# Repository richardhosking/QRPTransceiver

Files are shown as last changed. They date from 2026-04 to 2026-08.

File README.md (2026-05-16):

# QRPTransceiver

QRPTransceiver is an HF transceiver project using phasing techniques, surface-mount components, KiCad hardware design files, and Raspberry Pi Pico firmware for control and user interface.

## Overview

The repository combines:

- **hardware design** in KiCad
- **firmware** for Raspberry Pi Pico using PlatformIO/Arduino
- **local oscillator control** using an SI5351
- **front-panel UI** using a rotary encoder, push buttons, and an ILI9341 TFT display

The design is centered on a phasing-based architecture for HF operation and is being developed as an integrated hardware/firmware system.

## Repository Structure

```text
.
├── firmware/
│   ├── src/                # Main firmware application
│   ├── lib/                # Firmware libraries (UI, input, SI5351 control, etc.)
│   ├── include/            # Shared firmware headers
│   ├── test/               # Firmware tests
│   ├── scripts/            # Utility scripts
│   └── platformio.ini      # PlatformIO project file
├── hardware/
│   ├── kicad/
│   │   ├── QRPTransceiver.kicad_pro
│   │   ├── QRPTransceiver.kicad_sch
│   │   ├── QRPTransceiver.kicad_pcb
│   │   ├── QRPTransceiver.pretty/   # Local footprint library
│   │   └── lib_sch/                 # Local symbol library files
│   └── outputs/            # Manufacturing outputs, exports, and generated artifacts
├── docs/
│   ├── architecture.md
│   ├── bringup.md
│   ├── calibration.md
│   ├── firmware-overview.md
│   ├── hardware-overview.md
│   ├── pinout.md
│   └── summaries/          # Summary notes and rework history
├── reference/
│   ├── datasheets/         # Reference component datasheets
│   └── licenses/           # License/reference documents
├── archive/
│   ├── backups/            # Backup zips, cache/rescue files, and *-bak artifacts
│   ├── legacy-kicad/       # Legacy KiCad schematic/netlist files
│   └── temporary/          # Autosave, lock, and temporary design files
└── README.md
```

The repository is now organized so that active firmware lives under `firmware/`, the active KiCad project lives under `hardware/kicad/`, generated hardware outputs live under `hardware/outputs/`, and reference material is stored under `reference/`.

## Main Subsystems

### Hardware
- main transceiver schematic and PCB
- hierarchical sheets for mixer, polyphase, and receiver audio sections
- local symbol and footprint libraries
- manufacturing outputs and design reports

### Firmware
- `firmware/src/main.cpp` as the control entry point
- `firmware/lib/DisplayUI` for the TFT display layer
- `firmware/lib/RotaryInput` for tuning encoder input
- `firmware/lib/PushButtons` for front-panel button handling
- `firmware/lib/SI5351Control` for synthesizer control and band-specific quadrature setup

## Documentation

Project documentation is organized under `docs/`:

- `docs/architecture.md` — overall system architecture
- `docs/bringup.md` — bring-up notes and observations
- `docs/calibration.md` — calibration workflow and notes
- `docs/hardware-overview.md` — hardware design structure and subsystem roles
- `docs/firmware-overview.md` — firmware organization and responsibilities
- `docs/pinout.md` — firmware-visible pin assignments
- `docs/summaries/` — summary notes for key refactors, programming flow, and quadrature correction work

## Current Status

The repository currently contains:
- active KiCad project files under `hardware/kicad/`
- firmware for Pico-based control and display under `firmware/`
- generated outputs under `hardware/outputs/`
- reference materials under `reference/`
- archived legacy, backup, and intermediate design artifacts under `archive/`

As the project evolves, the active KiCad project and PlatformIO firmware remain the primary editable sources in their dedicated subdirectories.

## Toolchain

### Hardware
- KiCad 8 project files are present under `hardware/kicad/`

### Firmware
- PlatformIO
- Arduino framework for Raspberry Pi Pico
- SI5351 library
- Adafruit GFX / ILI9341 display libraries

## Notes

This project is an active mixed-domain design spanning:

- RF/analog circuit design
- phasing-based transceiver architecture
- embedded firmware
- user interface development
- calibration and layout refinement

For architectural details, start with `docs/architecture.md`.

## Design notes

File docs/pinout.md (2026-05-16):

# QRPTransceiver Pinout

## 1. Scope

This document summarizes the firmware-visible pin assignments currently used by QRPTransceiver. These values are derived from the current firmware source and should be treated as the active software pin map unless hardware wiring is intentionally changed.

## 2. Raspberry Pi Pico Pin Usage Summary

## 2.1 Rotary encoder

- GP2 — rotary encoder A
- GP3 — rotary encoder B
- GP6 — rotary encoder push button

## 2.2 Front-panel buttons

- GP7 — MODE button
- GP8 — BAND button
- GP9 — STEP button
- GP10 — FN/SAVE button

## 2.3 TFT display

- GP16 — TFT MISO
- GP17 — TFT CS
- GP18 — TFT SCK
- GP19 — TFT MOSI
- GP20 — TFT DC
- GP21 — TFT RST
- GP22 — TFT backlight

## 2.4 Built-in indicator

- LED_BUILTIN — firmware heartbeat indicator

## 3. Functional Grouping

### User input
- GP2, GP3, GP6
- GP7, GP8, GP9, GP10

### Display / SPI-related
- GP16, GP17, GP18, GP19, GP20, GP21, GP22

### System status
- LED_BUILTIN

## 4. Notes

## 4.1 Input assumptions

The current firmware configures:

- rotary encoder pins with pull-ups
- encoder button with pull-up
- push buttons as active-low inputs with pull-ups

This means external wiring should match an active-low switch arrangement unless the firmware configuration is changed.

## 4.2 Push-button defaults

The push-button library default configuration supports:

- MODE
- BAND
- STEP
- FN

The main application currently initializes FN on GP10.

## 4.3 Display assumptions

The display layer is written for an ILI9341-compatible TFT and uses the pin assignments listed above. The firmware also references display probe reads and a landscape orientation UI.

## 4.4 SI5351 interface

The current firmware clearly initializes the SI5351, but the specific GPIO pins used for its control bus are not explicitly documented in the currently reviewed source snippets. On Raspberry Pi Pico Arduino builds, these may rely on the framework's default I2C pin mapping unless overridden elsewhere.

That interface should be documented explicitly once confirmed in the hardware or complete firmware configuration.

## 5. Recommended Next Step

This file should eventually be expanded with:

- SI5351 bus pins
- power-related pins if relevant
- connector names
- schematic reference designators for major interfaces
- a table cross-referencing Pico pin numbers, GPIO names, and physical connector locations

## 6. Summary Table

| Function | GPIO |
|---|---|
| Encoder A | GP2 |
| Encoder B | GP3 |
| Encoder Button | GP6 |
| MODE Button | GP7 |
| BAND Button | GP8 |
| STEP Button | GP9 |
| FN/SAVE Button | GP10 |
| TFT MISO | GP16 |
| TFT CS | GP17 |
| TFT SCK | GP18 |
| TFT MOSI | GP19 |
| TFT DC | GP20 |
| TFT RST | GP21 |
| TFT Backlight | GP22 |
| Heartbeat LED | LED_BUILTIN |

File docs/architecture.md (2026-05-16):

# QRPTransceiver Architecture

## 1. Purpose

QRPTransceiver is a low-power HF transceiver project that combines:

- an analog phasing-based RF/baseband architecture
- SI5351-based local oscillator generation
- Raspberry Pi Pico digital control
- a TFT-based user interface
- KiCad hardware design files and PlatformIO-based firmware

The repository currently contains both the hardware design and the firmware used to control the synthesizer, user input devices, and display.

## 2. Project Goals

The current design appears to target the following goals:

- build a compact HF SSB transceiver
- use phasing techniques rather than a conventional crystal IF
- support multiple amateur HF bands
- provide digitally controlled tuning and band/mode selection
- use low-cost and widely available components
- keep the firmware modular enough to separate UI, tuning input, and synthesizer control

## 3. High-Level System Overview

At a high level, the system is organized into these major subsystems:

1. **RF and analog signal path**
   - receives and processes RF signals
   - performs phasing/mixing operations
   - routes signal energy through receiver audio/baseband stages

2. **Quadrature frequency generation**
   - generates the LO signals required by the phasing architecture
   - uses the SI5351 clock generator as the main frequency source
   - applies band-specific quadrature setup logic in firmware

3. **Control firmware**
   - maintains VFO frequency, band, and mode state
   - handles persistent settings storage
   - coordinates synthesizer, display, buttons, and rotary input

4. **User interface**
   - presents frequency and mode information on an ILI9341 TFT display
   - allows tuning and control through a rotary encoder and push buttons

5. **Hardware documentation and manufacturing outputs**
   - KiCad schematic and PCB files
   - generated Gerbers, PDFs, and reports
   - reference datasheets and design notes

## 4. Repository-Level Architecture

The repository contains two tightly coupled but distinct domains:

### 4.1 Hardware design domain

The hardware domain is centered on KiCad project files, including:

- main project and board files
- top-level hierarchical schematic
- subsystem schematics such as mixer, polyphase, and receiver audio sections
- PCB layout
- footprint and symbol libraries
- manufacturing outputs and reports

This domain defines the transceiver's electrical implementation and board layout.

### 4.2 Firmware domain

The firmware domain is a PlatformIO/Arduino-style codebase for Raspberry Pi Pico. It contains:

- application entry point in `src/`
- reusable libraries in `lib/`
- headers in `include/`
- scripts and tests
- configuration in `platformio.ini`

This domain implements the runtime behavior of the transceiver controller.

## 5. Hardware Architecture

## 5.1 Top-level schematic structure

The KiCad top-level schematic is organized using hierarchical sheets. The important hardware blocks currently visible in the design are:

- main transceiver sheet
- mixer section
- polyphase section
- receiver audio section

This indicates a design where the signal path is intentionally partitioned into functional analog subsystems.

## 5.2 RF / phasing concept

The project is described as an **SSB HF transceiver using phasing techniques**. In practical terms, this implies:

- quadrature-related signal generation and processing are central to the design
- the mixer and polyphase sections are likely responsible for phase relationships used to reject the unwanted sideband
- sideband suppression depends on maintaining amplitude and phase accuracy across the signal chain

Because phasing architectures are sensitive to imbalance, calibration and layout discipline are important parts of the overall architecture.

## 5.3 Main analog subsystems

### Mixer subsystem

The mixer subsystem is expected to:

- combine RF and local oscillator signals
- generate or recover quadrature baseband/audio components
- participate in sideband selection or rejection depending on signal direction

This block should be treated as one of the primary RF-critical sections of the design.

### Polyphase subsystem

The polyphase subsystem is expected to:

- generate or process 90-degree phase-shifted signals
- support phasing-based image or sideband cancellation
- define frequency-sensitive analog behavior that may need tuning or characterization

This is a core architectural block for any phasing transceiver.

### Receiver audio subsystem

The receiver audio subsystem is expected to:

- filter and amplify low-frequency recovered signals
- condition audio for monitoring or downstream processing
- provide an analog endpoint for receive-path verification during bring-up

This block is a natural place for gain shaping, filtering, and audio output conditioning.

## 5.4 PCB architecture

The PCB file indicates the project includes a board layout and manufacturing outputs. At an architectural level, the PCB should be understood as containing at least these physical partitions:

- RF-sensitive analog paths
- local oscillator / clock routing
- audio/baseband analog stages
- digital control and display connections
- power distribution and grounding

For maintainability and performance, the layout should preserve clear separation between noisy digital circuits and sensitive analog/RF sections.

## 6. Frequency Generation and Synthesizer Architecture

## 6.1 SI5351 as the main LO source

The firmware includes a dedicated `SI5351Control` library. This makes the SI5351 the primary digital frequency source for the transceiver.

Responsibilities of this subsystem include:

- initializing the SI5351
- setting VFO frequency
- enabling/disabling outputs
- configuring band-specific quadrature behavior
- exposing synthesizer readiness and current frequency state

## 6.2 Band-aware quadrature control

The synthesizer code defines band profiles for amateur bands including:

- 160 m
- 80 m
- 40 m
- 30 m
- 20 m
- 17 m
- 15 m
- 12 m
- 10 m

This suggests that quadrature generation is not handled as a single generic configuration but is tuned using precomputed band profiles.

Architecturally, this is important because it means:

- the LO subsystem contains band-specific knowledge
- frequency generation and phase behavior are part of the firmware design, not only hardware
- calibration may differ by band

## 6.3 Frequency correction model

The firmware includes a crystal correction value in parts-per-billion. This means the architecture already acknowledges oscillator error and compensates it in software.

This is a strong architectural choice because it allows:

- post-assembly calibration
- compensation for crystal tolerance
- easier alignment without hardware modification

## 7. Firmware Architecture

## 7.1 Firmware responsibilities

The firmware acts as the control plane for the transceiver. It is responsible for:

- initializing hardware peripherals
- maintaining tuning state
- managing frequency bands and step sizes
- controlling the display
- reading user input
- storing and restoring persistent settings
- programming the SI5351 synthesizer

The firmware is not just a UI layer; it is the coordination layer that makes the analog hardware usable as a complete radio.

## 7.2 Main application layer

The main application code in `src/main.cpp` appears to manage:

- current VFO frequency
- current operating mode
- allowed tuning range
- step sizes
- default frequencies per band
- current band index
- dirty-state tracking for persistent settings

This is effectively the system state model of the transceiver.

## 7.3 Library-based modularity

The firmware already uses separate libraries for major functions:

### DisplayUI

Responsibilities:

- initialize and access the ILI9341 display
- configure orientation and display settings
- render splash and main screens
- update frequency and mode display fields

This module is the presentation layer.

### RotaryInput

Responsibilities:

- initialize the rotary encoder interface
- decode Gray-code transitions
- detect button presses
- control tuning step size

This module is the primary tuning input layer.

### PushButtons

Responsibilities:

- read additional front-panel buttons
- support mode, band, and step selection
- provide button events to the main application layer

### SI5351Control

Responsibilities:

- initialize clock generation
- apply band-specific profiles
- set VFO frequency
- manage output enable state
- report synthesizer status

This module is the frequency-control layer.

## 7.4 Persistent settings

The main firmware includes flash-backed settings with a magic value and version field. Architecturally, this means the transceiver preserves user state across power cycles.

Likely persistent state includes:

- selected band
- per-band frequencies
- current tuning configuration
- other user preferences as the firmware evolves

This is a good fit for a radio UI, since users expect frequency memories and last-used settings to be retained.

## 8. User Interface Architecture

## 8.1 Physical controls

The interface includes:

- a rotary encoder with push button
- three additional push buttons
- a TFT display

This creates a compact front-panel interaction model suitable for a small transceiver.

## 8.2 Display model

The UI library currently supports:

- splash screen
- main operating screen
- frequency display updates
- mode display
- status bar regions
- placeholder S-meter area

This suggests a screen architecture based on a single main operating view rather than a menu-heavy system.

## 8.3 UI state and operating model

The present interaction model appears to be:

- rotary encoder changes VFO frequency
- button actions change step, mode, or band
- screen redraws reflect current operating state

A future evolution could formalize this into an explicit UI state machine, but the current architecture is suitable for a single-purpose front panel.

## 9. Operating Modes and Band Model

The current mode model includes:

- LSB
- USB
- CW
- FT8
- WSPR

This is an interesting architectural choice because it separates **display/operating intent** from pure RF hardware details. It suggests the firmware is intended to support multiple operating styles, even if some modes share the same underlying analog path.

The band model currently includes amateur band defaults and remembers a working frequency per band. This is a practical radio control feature and should remain a first-class concept in the architecture.

## 10. Data and Control Flow

## 10.1 Control flow from user input to frequency output

A typical tuning flow is:

1. user rotates encoder
2. rotary module produces a step delta
3. main application applies the selected tuning step
4. VFO frequency is updated
5. synthesizer is reprogrammed
6. display is updated to reflect the new frequency and mode

This path is the central interaction loop of the system.

## 10.2 Control flow for band/mode changes

A typical band or mode change flow is:

1. user presses a control button
2. main application updates current mode or band index
3. band default or stored band frequency is restored
4. synthesizer is reconfigured if needed
5. display is refreshed

## 10.3 Boot flow

A probable boot sequence is:

1. initialize MCU runtime
2. initialize display and draw splash screen
3. initialize input devices
4. load persistent settings from flash
5. initialize SI5351 with configured correction
6. apply default or restored VFO frequency and mode
7. draw main screen

## 11. Calibration Architecture

Calibration is not an optional add-on for this design; it is part of the architecture.

Important calibration concerns include:

- SI5351 absolute frequency correction
- quadrature phase accuracy
- gain balance between I/Q or phasing paths
- sideband suppression verification
- per-band behavior

The existing crystal correction approach shows that firmware-assisted calibration is already part of the design philosophy.

A dedicated calibration procedure document should exist alongside this architecture.

## 12. Design Constraints and Tradeoffs

The design appears to balance several constraints:

### Low-cost and availability
Using Raspberry Pi Pico, SI5351, and common display modules keeps the platform accessible.

### Simplicity vs. performance
A phasing architecture can reduce reliance on IF filters but introduces sensitivity to analog balance and calibration.

### Modular firmware
The firmware is organized cleanly into libraries, which supports iterative improvement.

### Mixed-domain complexity
The project spans analog RF design, phasing concepts, digital control, PCB layout, and UI, which means architectural clarity is especially important.

## 13. Known Architectural Gaps

Based on the current repository, these areas need clearer design documentation:

- explicit receive signal path description
- whether transmit is already implemented in hardware or only planned
- exact relationship between quadrature synthesis and analog phasing network
- power architecture and regulator scheme
- front-panel control mapping
- calibration workflow by band
- test strategy for RF, LO, and audio subsystems

These gaps do not necessarily reflect design problems, but they do reduce maintainability and onboarding ease.

## 14. Recommended Canonical Architecture Organization

To make the architecture easier to maintain, the repository should treat the following as canonical:

### Hardware source of truth
- current KiCad 8 project files
- hierarchical schematics
- current PCB layout
- local symbol and footprint libraries

### Firmware source of truth
- `platformio.ini`
- `src/`
- `lib/`
- `include/`
- `test/`

### Generated outputs
- Gerbers
- PDFs
- DRC reports

### Archived artifacts
- old KiCad legacy-format files
- autosaves
- backups
- copied project files
- cache files

## 15. Recommended Next Documentation

This architecture file should be accompanied by:

- `docs/hardware-overview.md`
- `docs/firmware-overview.md`
- `docs/bringup.md`
- `docs/calibration.md`
- `docs/pinout.md`
- `docs/block-diagram.md`

## 16. Summary

QRPTransceiver is a mixed hardware/firmware transceiver project built around a phasing-based HF architecture. Its defining characteristics are:

- analog phasing signal processing
- SI5351-based quadrature-oriented local oscillator control
- Raspberry Pi Pico-based digital coordination
- modular firmware for UI, tuning input, and synthesizer control
- integrated KiCad board and schematic design files

The project already has a solid modular foundation in both hardware hierarchy and firmware library structure. The main architectural need now is not a redesign of the system itself, but clearer documentation, stronger separation of canonical files from generated or legacy artifacts, and explicit documentation of signal flow, calibration, and subsystem boundaries.

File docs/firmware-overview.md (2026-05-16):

# QRPTransceiver Firmware Overview

## 1. Scope

This document describes the structure and responsibilities of the QRPTransceiver firmware. The firmware runs on a Raspberry Pi Pico and provides the control layer for tuning, user interaction, display output, and SI5351 frequency generation.

## 2. Firmware Role in the System

The firmware is the operational control plane of the transceiver. It is responsible for making the hardware usable as a radio by coordinating:

- VFO tuning
- band selection
- operating mode selection
- synthesizer configuration
- user input handling
- front-panel display output
- persistent settings storage

Without the firmware, the hardware design is a set of subsystems; with the firmware, those subsystems become an interactive transceiver platform.

## 3. Firmware Technology Stack

The repository indicates a firmware stack based on:

- Raspberry Pi Pico
- PlatformIO
- Arduino-compatible framework
- external device libraries for the display and SI5351

The code is structured in a modular embedded style rather than as a single monolithic application file.

## 4. Repository Layout

The firmware-related repository structure currently includes:

- `src/` — application entry point and top-level behavior
- `lib/` — modular libraries for display, rotary input, buttons, and synthesizer control
- `include/` — shared headers
- `test/` — tests
- `scripts/` — helper scripts
- `platformio.ini` — firmware build and configuration entry point

This is a good foundation for maintainable firmware development.

## 5. Main Responsibilities

The firmware currently appears to implement these major responsibilities:

### 5.1 System initialization
- initialize runtime and peripherals
- initialize display
- initialize input devices
- initialize SI5351 synthesizer
- restore or initialize operating state

### 5.2 Frequency control
- maintain the current VFO frequency
- apply minimum and maximum tuning limits
- support different tuning step sizes
- remember working frequencies for each band

### 5.3 Mode and band control
- track current operating mode
- change band defaults or stored band frequencies
- update display and synthesizer state after control changes

### 5.4 User interface control
- render splash and main screens
- update frequency and mode display fields
- reflect transceiver state visually

### 5.5 Persistent settings
- save settings to flash
- restore settings at boot
- track dirty state and versioning

## 6. Main Application Architecture

## 6.1 `src/main.cpp`

The main application layer acts as the system coordinator. It appears to hold or manage:

- current VFO frequency
- current mode
- valid tuning range
- tuning step table
- band default frequencies
- currently selected band
- settings persistence metadata

This file is the central state-management and orchestration layer of the firmware.

## 6.2 Application state model

The firmware already has the beginnings of a coherent state model. Important state elements include:

- current frequency
- current mode
- current band
- selected tuning step
- per-band stored frequencies
- settings dirty flag

This state should be treated as the canonical runtime model for the transceiver.

## 7. Modular Library Architecture

The firmware is split into reusable libraries under `lib/`. This is one of the strongest parts of the current design.

## 7.1 DisplayUI

The `DisplayUI` module is responsible for the front-panel display layer.

Current responsibilities include:

- providing access to the display instance
- display initialization
- reading display probe data
- UI configuration
- drawing splash and main screens
- updating the visible frequency and mode

Architecturally, this module should remain focused on presentation rather than business logic.

### Recommended boundary
`DisplayUI` should:
- draw UI state
- format visual elements
- own screen layout details

`DisplayUI` should not:
- decide operating policy
- own VFO truth
- perform synthesizer logic

## 7.2 RotaryInput

The `RotaryInput` module handles tuning encoder behavior.

Current responsibilities include:

- GPIO setup for encoder pins
- Gray-code decoding
- directional step detection
- encoder button edge detection
- tuning step value management

Architecturally, this module is the low-level physical input decoder for the main tuning control.

### Recommended boundary
`RotaryInput` should:
- read hardware state
- return delta steps and button events

`RotaryInput` should not:
- directly change frequency
- directly update the display
- contain band or mode logic

## 7.3 PushButtons

The `PushButtons` module is intended to handle the additional front-panel buttons.

Expected responsibilities include:

- reading non-encoder button states
- debouncing or edge detection
- converting button actions into application-level events

This module should be the companion input layer to the rotary encoder.

## 7.4 SI5351Control

The `SI5351Control` module is responsible for the programmable oscillator subsystem.

Current responsibilities include:

- initializing the SI5351
- accepting configuration such as crystal frequency and correction
- setting VFO frequency
- configuring quadrature-related output behavior
- applying band-specific profiles
- enabling or disabling outputs
- reporting readiness and current VFO value

This module is the firmware's abstraction over the LO hardware.

### Recommended boundary
`SI5351Control` should:
- own synthesizer device behavior
- translate desired frequency state into SI5351 operations
- contain band profile and correction logic

`SI5351Control` should not:
- own screen rendering
- own button interpretation
- decide UI workflow

## 8. Operating Model

## 8.1 Tuning workflow

The normal tuning loop is expected to be:

1. read encoder movement
2. convert movement into signed tuning steps
3. scale by selected tuning resolution
4. clamp to valid range
5. update VFO state
6. program SI5351 to new frequency
7. refresh display

This is the highest-frequency control loop in the application.

## 8.2 Band-change workflow

The normal band-change flow is expected to be:

1. detect button event
2. increment or select band
3. restore stored or default frequency for that band
4. apply synthesizer configuration changes
5. update visible UI fields

## 8.3 Mode-change workflow

The normal mode-change flow is expected to be:

1. detect button event
2. update mode state
3. refresh any derived behavior or display fields
4. keep the mode visible on the main screen

## 9. Frequency and Band Model

The firmware includes:

- a valid tuning range from low HF through 6 m
- a step table with multiple resolutions
- default frequencies for multiple amateur bands
- retained per-band frequency state

This is a sound operating model for a compact radio because it allows:

- quick tuning changes
- predictable band recall
- user-friendly control behavior

## 10. Persistent Settings Architecture

The firmware includes flash-backed settings identified by:

- a magic value
- a version field

This is the right foundation for reliable on-device persistence.

A robust persisted settings model should eventually include:

- current band
- current frequency or per-band frequencies
- tuning step selection
- selected mode
- calibration/configuration values if appropriate

Versioning is important so settings can evolve safely as firmware changes.

## 11. UI Architecture

## 11.1 Current UI model

The current display model appears to center on a single primary operating screen with:

- frequency display
- mode area
- band area
- status bar
- S-meter placeholder

This is well suited to a compact hardware front panel.

## 11.2 Recommended UI layering

The UI architecture will remain easier to maintain if it is split conceptually into:

### View model
A simple representation of what should be shown:
- frequency text
- mode text
- band text
- status fields

### Rendering layer
The actual display drawing code in `DisplayUI`

### Application controller
Main logic that decides when the view model changes

This reduces coupling between control logic and drawing logic.

## 12. Error Handling and Robustness

Firmware for a radio controller should handle at least these fault conditions gracefully:

- SI5351 initialization failure
- display initialization or communication problems
- invalid or corrupt flash settings
- out-of-range frequency requests
- input bounce or noisy encoder transitions

The current modular architecture makes it practical to improve robustness incrementally.

## 13. Recommended Future Refactoring Directions

The current structure is already solid, but future improvements could include:

### 13.1 Explicit application state struct
Move global state into a structured object such as:
- VFO
- band
- mode
- step
- persistent settings metadata

### 13.2 Event-driven input handling
Represent button and encoder actions as explicit events rather than direct inline mutations.

### 13.3 UI view model
Create a lightweight UI data model that the renderer consumes.

### 13.4 Hardware abstraction consistency
Ensure all hardware-facing code stays inside dedicated modules rather than leaking into `main.cpp`.

### 13.5 Centralized calibration/config structure
Store synthesizer correction, band offsets, and similar tunable values in a dedicated configuration layer.

## 14. Testing Opportunities

The presence of a `test/` directory means the project can grow into more systematic validation. Useful firmware tests would include:

- step-size logic
- frequency clamping
- band-memory behavior
- mode cycling behavior
- settings serialization/deserialization
- band profile selection logic
- frequency formatting for display

Even if hardware access remains manual, core logic can be validated independently.

## 15. Recommended Firmware Documentation Additions

In addition to this overview, useful companion documents would be:

- `docs/pinout.md`
- `docs/bringup.md`
- `docs/calibration.md`
- `docs/ui-behavior.md`
- `docs/settings-format.md`

## 16. Summary

The QRPTransceiver firmware is a modular embedded control system for a phasing-based HF transceiver. Its central role is to coordinate:

- tuning and band/mode state
- SI5351 frequency generation
- user input from encoder and buttons
- ILI9341 display output
- persistence of radio operating state

The current separation into `DisplayUI`, `RotaryInput`, `PushButtons`, and `SI5351Control` is a strong architectural base. The main next steps are clearer documentation, slightly more explicit state modeling, and continued separation between application logic, rendering, and hardware control.

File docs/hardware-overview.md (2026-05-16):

# QRPTransceiver Hardware Overview

## 1. Scope

This document describes the hardware organization of the QRPTransceiver project at the repository and subsystem level. It is intended as a guide to how the hardware design is partitioned, what the major blocks are, and how to navigate the KiCad sources.

## 2. Hardware Design Artifacts

The hardware design currently includes:

- KiCad project file
- top-level schematic
- PCB layout
- hierarchical schematic sheets
- local footprint and symbol libraries
- Gerber outputs
- PDF exports
- DRC and related reports
- datasheet references

These files collectively define the electrical design, physical PCB implementation, and manufacturing outputs.

## 3. Primary Hardware Source Files

The main editable hardware sources should be treated as:

- `QRPTransceiver.kicad_pro`
- `QRPTransceiver.kicad_sch`
- `QRPTransceiver.kicad_pcb`

These should be considered the primary design source of truth.

Additional subsystem schematics currently include:

- `ReceiverAudio.kicad_sch`
- `polyphase.kicad_sch`

The top-level schematic also references additional hierarchical sheet structure for mixer-related circuitry.

## 4. Design Philosophy

The hardware appears to follow a phasing-based HF transceiver approach. This implies a design philosophy built around:

- quadrature signal generation or processing
- analog amplitude and phase balance
- modular RF/baseband partitioning
- digital assistance for tuning and control
- practical PCB implementation using surface-mount components

Compared with a more traditional IF-filter-centered transceiver, this architecture places more importance on phase accuracy and subsystem matching.

## 5. Hardware Partitioning

The design can be understood as a set of major hardware blocks.

## 5.1 RF front end

The RF front end is expected to include:

- antenna-side signal entry
- input filtering or band-dependent response
- routing into the mixer/phasing path
- any switching required between operating conditions

This is the section most exposed to external RF conditions and should be treated as a sensitive analog block.

## 5.2 Mixer section

The mixer section is a central transceiver block. Its role is expected to include:

- translation between RF and lower-frequency signal domains
- interaction with quadrature local oscillator signals
- support for sideband-selective behavior through phasing techniques

This section is tightly coupled to the quality of the LO generation and the analog balance of the signal path.

## 5.3 Polyphase section

The polyphase section is one of the defining features of the design. It is expected to:

- establish controlled phase relationships between signal paths
- contribute to image or sideband suppression
- shape the frequency-dependent phase behavior required by the phasing architecture

This block is likely one of the most performance-sensitive parts of the analog design.

## 5.4 Receiver audio section

The receiver audio section is expected to:

- process recovered low-frequency or audio-band signals
- apply filtering and gain
- provide output suitable for listening, measurement, or further conditioning

This block is a key bring-up checkpoint because it allows observation of downconverted receive-path behavior.

## 5.5 Control and digital interface section

The design also includes a digital control domain built around a Raspberry Pi Pico and peripheral modules. This section likely includes:

- MCU connections
- SI5351 control interface
- display connections
- rotary encoder input
- push-button input
- power and reset support for digital peripherals

Although digital, this section directly influences RF usability through frequency control and operating-state selection.

## 6. Frequency Generation Hardware

## 6.1 SI5351 role

The SI5351 is the central programmable oscillator element in the design. Its hardware role is to provide the clock or LO signals required by the transceiver.

In a phasing design, this is especially important because the quality and phase relationship of generated signals directly affect sideband suppression and tuning usability.

## 6.2 Quadrature implications

The firmware organization suggests the hardware depends on band-specific quadrature behavior. That implies the hardware and firmware together form a combined frequency-generation subsystem rather than fully independent analog and digital sections.

This combined subsystem should be treated as a unified design concern during:
- bring-up
- calibration
- troubleshooting
- future revisions

## 7. PCB-Level Considerations

## 7.1 Physical separation of domains

For best performance, the board should maintain clear physical separation between:

- RF analog paths
- audio/baseband analog paths
- clock/LO routing
- digital control and display wiring
- power conversion or regulation areas

This reduces the risk of digital noise degrading analog performance.

## 7.2 Grounding and return paths

Because the project combines analog RF and digital control on one board, grounding strategy is likely to be a key factor in performance. Review areas should include:

- return current paths
- analog/digital interaction zones
- display and SPI noise coupling
- oscillator signal reference quality
- audio-stage grounding

## 7.3 Routing priorities

Routing priorities should generally favor:

- short and controlled LO paths
- clean sensitive analog routing
- separation of switching digital lines from high-gain analog stages
- careful placement of decoupling components
- consistent grounding around the mixer and polyphase networks

## 8. Hardware Interfaces

The major hardware interfaces in the project are expected to include:

### RF interfaces
- antenna and RF signal path connections
- any band-related or signal-routing interconnects

### Audio interfaces
- receiver audio output
- internal analog handoff points between mixer/polyphase/audio sections

### Digital control interfaces
- I2C or similar control connection to SI5351
- SPI connection to TFT display
- GPIO for encoder and buttons

### Power interfaces
- primary supply input
- regulated rails for analog and digital sections
- display backlight and digital peripheral supply distribution

## 9. Bring-Up Strategy by Hardware Block

A practical hardware validation order is:

1. **power rails**
   - confirm supply integrity and regulator outputs

2. **MCU and control section**
   - verify Pico boots and firmware runs

3. **display and inputs**
   - verify user interface hardware functions

4. **SI5351 / LO section**
   - verify oscillator programming and output frequency

5. **receiver audio path**
   - confirm analog audio stages are alive and stable

6. **mixer and quadrature network**
   - verify expected translation and phase-related behavior

7. **full receive chain**
   - validate end-to-end tuning and signal reception

This staged bring-up reduces ambiguity during troubleshooting.

## 10. Hardware Risks and Sensitivities

The most likely architecture-level hardware sensitivities are:

- quadrature phase accuracy
- gain or component tolerance mismatch across phasing paths
- oscillator frequency error
- coupling from digital display/control lines into analog sections
- grounding/layout effects on sideband suppression
- variation in performance across bands

These are normal concerns for a phasing-based mixed-signal transceiver and should be explicitly measured during testing.

## 11. Recommended Hardware Documentation Additions

The hardware design would benefit from dedicated supporting documents such as:

- `docs/block-diagram.md`
- `docs/pinout.md`
- `docs/power.md`
- `docs/calibration.md`
- `docs/bringup.md`
- `docs/layout-notes.md`

In addition, the top-level schematic hierarchy should use clearly descriptive sheet names so the functional structure is visible directly inside KiCad.

## 12. Recommended Canonical Hardware Organization

As the repo evolves, the hardware should ideally be organized so that:

- active KiCad 8 files are grouped together
- generated outputs are separated from source design files
- local libraries are clearly grouped
- archived backups and legacy KiCad files are moved out of the active design path
- reports and exports are treated as generated artifacts rather than editable design source

A future structure could look like:

```text
hardware/
  kicad/
    QRPTransceiver.kicad_pro
    QRPTransceiver.kicad_sch
    QRPTransceiver.kicad_pcb
    sheets/
    libraries/
  outputs/
    gerbers/
    pdf/
    drc/
reference/
  datasheets/
archive/
  legacy-kicad/
  backups/
```

## 13. Summary

The QRPTransceiver hardware is organized around a phasing-based HF transceiver architecture with a strong division between:

- mixer and phasing circuitry
- receiver audio processing
- programmable LO generation
- digital control and user interface

Its success depends not only on correct schematic connectivity, but also on careful quadrature behavior, calibration, and PCB partitioning between analog and digital domains.

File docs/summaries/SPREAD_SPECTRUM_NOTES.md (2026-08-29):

 # Si5351 Spread-Spectrum (SSC) Notes

Last edited: 29 August 2026

Overview
--------
These notes collect the investigation, observed behaviour, and recommended
actions related to spread-spectrum clocking (SSC) on Si5351 modules encountered
during development of the QRPTransceiver firmware.

Background
----------
- Several Si5351 modules in the field and in development were found to power
  up with non-zero SSC parameter registers. The Etherkit `Si5351` library used
  by this project does not expose or manage SSC parameters.
- When active, SSC can impart deterministic spread or sidebands around the
  output clock that appeared as fixed-offset spurs in the receiver spectrum.

What we observed
----------------
- Fixed-offset sidebands (tens of kHz in these modules) that tracked with
  certain tuning operations and output drive transitions.
- After clearing all SSC parameter registers (registers `149..161`) the
  prominent sidebands disappeared and tuning noise characteristics improved.

What we changed (current firmware)
----------------------------------
- On init, the firmware explicitly writes `0x00` to `SI5351_SSC_PARAM0`..`SI5351_SSC_PARAM12`.
  This ensures SSC is effectively disabled for modules that power up with SSC
  enabled. The change is in `lib/SI5351Control/src/SI5351Control.cpp`.

Pros and cons of the current approach
-------------------------------------
- Pros:
  - Simple and reliable: clears any previously-enabled SSC quickly.
  - Eliminated the fixed sidebands observed during testing.

- Cons / Risks:
  - It's a blunt instrument: zeroing all SSC parameters removes any
    intentionally configured SSC behaviour and may hide vendor-specific
    calibration values.
  - Different module vendors may implement SSC-related behaviours slightly
    differently; overwriting all SSC parameters is not guaranteed to be
    appropriate for every board.

Recommended alternatives
------------------------
1. Selective disable
   - Prefer reading the SSC parameter registers at init and selectively
     clearing only the SSC enable/control bits per the SiLabs AN619 description
     if available. This preserves other SSC tuning parameters while disabling
     the spreading behaviour.

2. Preserve & log
   - Read SSC parameter registers on first boot, stash the original values in
     flash or in the serial log, then clear only the enable fields. This gives
     a reproducible rollback path for debugging.

3. External reference
   - If absolute spectral purity is a priority for production units, consider
     switching to an external reference (CLKIN) or using a higher-grade XO or
     TCXO; then set the Si5351 ref/correction appropriately.

Helpful engineering checks
-------------------------
- Read current SSC registers (example pseudo):

  ```cpp
  for (uint8_t r = SI5351_SSC_PARAM0; r <= SI5351_SSC_PARAM12; ++r) {
    Serial.print(r); Serial.print(": ");
    Serial.println(si5351_read(r), HEX);
  }
  ```

- If you see non-zero values, consider logging them before clearing.

Where to from here
-------------------
- I can implement any of the alternatives above:
  - selective disable (read/modify/write of specific bits),
  - persistent backup of SSC values to flash before clearing,
  - or a small serial calibration tool to read/write registers interactively.

If you'd like, tell me which option you prefer and I will implement it and
open a PR with the changes.

References
----------
- Silicon Labs AN619 application note (Si5351 programming guidance)
- Etherkit Si5351 library (no SSC management exposed)
SPREAD SPECTRUM NOTES
=====================

Summary
-------
Some SI5351 modules come from different vendors with spread-spectrum (SSC) features
enabled by default. This can add AM-like sidebands (observed at ±31.5 kHz) on the LO.

Mitigation
----------
- The firmware explicitly clears the SI5351 SSC parameter registers at init to ensure
  spread-spectrum is disabled on modules that power up with it enabled. The register
  range cleared is `SI5351_SSC_PARAM0` .. `SI5351_SSC_PARAM12` (addresses 149..161).
- This is a pragmatic fix; clearing SSC changes the synthesizer behaviour and will
  alter absolute-frequency calibration. The firmware therefore exposes a trim
  (`SI5351_CORRECTION_TRIM_PPB`) that can be adjusted per-board to restore
  absolute frequency accuracy after SSC is disabled.

Open Questions / Follow-ups
---------------------------
- Clearing the full parameter block is aggressive — a cleaner approach would be to
  read-modify-write only the SSC enable bit if the device supports it. This would
  preserve other SSC parameters while ensuring SSC is disabled.
- Consider adding an automated calibration routine to measure and persist the
  `SI5351_CORRECTION_TRIM_PPB` per board to account for module-to-module variation
  and temperature drift.

References
----------
- Etherkit Si5351 headers define the SSC registers but the library README marks
  spread-spectrum as "unsupported". See `lib/SI5351Control/src/SI5351Control.cpp`
  for the current zeroing implementation in `beginDevice()`.
# SI5351 Spread-Spectrum (SSC) Notes

Purpose
-------
Document the root cause analysis, evidence and practical options related to
spread-spectrum clocking (SSC) observed on some Si5351 modules during
development of the QRPTransceiver V3 firmware.

Symptoms observed
-----------------
- Fixed-offset sidebands and spurs (e.g. ~31 kHz offsets) appearing on outputs
  when certain tuning strategies or output power transitions occurred.
- Problem more visible with higher output drive and when using the direct
  phase-register quadrature tuning method on higher bands.

Root cause
----------
- Some third-party Si5351 modules power up with non-zero SSC parameter
  registers; the upstream Etherkit library does not manage SSC state.
- Active SSC + frequent multisynth/PLL changes produced measurable spurs and
  changed apparent tuning/phase behaviour.

Workaround applied
------------------
1. Firmware explicitly clears SSC parameter registers on init:

   - Registers `SI5351_SSC_PARAM0` .. `SI5351_SSC_PARAM12` are zeroed during
     `beginDevice()` so modules that power with SSC enabled are forced to a
     non-SSC state.

2. Tuning strategy changed to a fixed-divider + PLL retune method for all
   bands, which reduced interaction with any residual SSC state and lowered
   audible step noise.

Risks and trade-offs
--------------------
- Zeroing all SSC params is an aggressive action. It guarantees SSC is off but
  also discards any intentional SSC configuration some hardware might rely on.
- Alternative: toggle only the SSC enable bit if future testing shows a
  reliable documented bit for enabling/disabling SSC across vendor modules.

Recommended future actions
-------------------------
1. If module compatibility is required across many part vendors, prefer toggling
   only the SSC enable bit (if present/documented) rather than zeroing all SSC
   parameters. This requires additional testing to find the correct control
   register/bit across modules.

2. Add a diagnostic readback option during init to log SSC parameter values to
   serial for failure analysis; helpful when field reproducers report spurs.

3. For production-grade frequency accuracy, use an external 10 MHz reference or
   temperature-stabilized crystal and configure the Si5351 to use `CLKIN` via
   `set_ref_freq()` and `set_pll_input()`.

4. Document the SSC-clear behaviour in `CURRENT_SI5351_APPROACH.md` and in the
   build/production notes so maintainers are aware of the side-effect.

Files & locations
-----------------
- Implementation: `lib/SI5351Control/src/SI5351Control.cpp` (SSC clear loop)
- Summary reference: `docs/summaries/QUADRATURE_PHASE_CORRECTION_SUMMARY.txt`

End of notes

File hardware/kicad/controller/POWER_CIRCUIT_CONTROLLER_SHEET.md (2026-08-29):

# Controller Sheet — Processor Power Latch (Draft)
Date: 2026-08-29

This file is a draft representation of the processor power-latch circuit placed
into the project's `controller` KiCad sheet. It is intended to be used as the
source for creating a proper KiCad schematic sheet (`.kicad_sch`) by copying
the components and nets into your KiCad project.

See also: [hardware/kicad/drafts/POWER_CIRCUIT_SCHEMATIC_DRAFT.md](../kicad/drafts/POWER_CIRCUIT_SCHEMATIC_DRAFT.md)

SHEET: Controller / Power Latch

Symbols / Refdes
- Q1: PMOS_HIGH (AO3407A) — high-side P-channel MOSFET
- Q2: NMOS_LOW (2N7002) — gate pull-down / latch driver
- R1: R_PU_GATE (1M) — gate pull-up to VIN
- R2: R_BTN_SER (1k) — optional series resistor from button to gate
- R3: R_Q2_G_PD (100k) — pull-down on Q2 gate
- C1: C_GATE_BYP (100nF) — gate bypass cap to VIN
- SW1: SW_POWER (momentary push)
- D1: D1_SCHOTTKY (optional) — Schottky from V_SYS to VIN (ESD/protect)
- U1: LDO_3V3 (optional) — regulator from V_SYS to 3V3

Net connections (KiCad net names)
- VIN       : connector VIN
- V_SYS     : net V_SYS (PMOS drain / LDO input)
- GATE_CTRL : net GATE_CTRL (PMOS gate, Q2 drain, button node)
- GND       : ground
- MCU_PWR_HOLD : net POWER_HOLD (MCU GPIO to Q2 gate)

Netlist sketch (human readable)

  VIN -----+--------------------+------------------------------
           |                    |                              
           |                   R1 (1M)                         
           |                    |                              
          Q1[S]                 +-- GATE_CTRL -----------------+
        PMOS (Q1)               |                             |
           |                    |                            C1
  V_SYS <--+--------------------+                            100nF
                                                              |
                                                             VIN

  SW1 between GATE_CTRL and GND (momentary)
  R2 optional series between SW1 and GATE_CTRL

  Q2: NMOS
    D -> GATE_CTRL
    S -> GND
    G -> MCU_PWR_HOLD (via 1k series if desired)
    R3 -> between Q2 G and GND

Expected behavior (firmware integration)
- Short press SW1: latch on sequence — MCU asserts `POWER_HOLD` high.
- Long press SW1: firmware mutes, saves state, clears `POWER_HOLD` to shut down.

Placement notes for the controller sheet
- Place Q1 close to the VIN connector on the sheet so the power flow is clear.
- Put decoupling caps (10 µF + 0.1 µF) on V_SYS near the LDO and MCU VCC pins.
- Draw the `POWER_HOLD` net to the MCU symbol on the controller sheet and label it.

Footprint suggestions (to be chosen in KiCad)
- Q1: SOT-23 P-MOS footprint
- Q2: SOT-23 N-MOSFET footprint
- LDO: SOT-223 or SOT-23-5 based on thermal needs
- Passives: 0603

Conversion note
- This file is intentionally human-readable; to integrate into an existing KiCad
  project, create a new sheet named `controller_power` and copy the symbols,
  nets, and footprints into that sheet. I can generate a `.kicad_sch` file if
  you want a machine-importable sheet — tell me and I'll produce one.

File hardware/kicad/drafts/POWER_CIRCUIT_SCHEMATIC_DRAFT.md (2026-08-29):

# Processor Power Section — Draft Schematic
Date: 2026-08-29

Purpose
- Draft schematic for the processor (RP2040) power section and power-latch circuit.
- Intended for review before creating a formal KiCad schematic sheet.

Overview
- VIN: external 5V (or other battery input) coming into board.
- V_SYS: regulated system rail (3.3V) powered through high-side PMOS latch Q1.
- POWER button: momentary push button used to latch power on/off via firmware.

Components
- Q1: P-channel MOSFET (high-side switch). Example: AO3407A or similar low-RdsON P-MOSFET.
- Q2: N-channel MOSFET (gate pull-down/latch driver). Example: 2N7002 or BSS138.
- R1: 1 MΩ pull-up from GATE_CTRL to VIN.
- R2: 1 kΩ series from button to GATE_CTRL (optional, for debouncing/noise suppression).
- R3: 100 kΩ pull-down on Q2 gate to GND.
- C1: 100 nF on GATE_CTRL to VIN for noise suppression (increase to 220 nF if needed).
- SW1: Momentary push button between GATE_CTRL and GND.
- D1: Schottky diode (optional) from V_SYS to VIN for ESD/protection.
- U1: LDO 3.3V regulator from V_SYS to VCC_3V3 (if separate regulation is used); alternatively V_SYS may be the LDO output.

Netlist sketch / connections
- VIN -> Q1 S (PMOS source)
- Q1 D -> V_SYS (PMOS drain to system rail/LDO input)
- Q1 G -> node GATE_CTRL
- R1 between GATE_CTRL and VIN (pull-up)
- C1 between GATE_CTRL and VIN (bypass)
- SW1 between GATE_CTRL and GND (momentary)
- R2 between SW1 and GATE_CTRL if series resistor used
- Q2 D -> GATE_CTRL
- Q2 S -> GND
- Q2 G -> MCU `POWER_HOLD` GPIO (through optional series resistor 1k)
- R3 between Q2 G and GND (pull-down)
- MCU `POWER_BUTTON` GPIO -> SW1 sense (through button to GND)
- Optionally place a small RC on the MCU input pin for debounce (10nF + 100k)

Suggested values and footprint notes
- PMOS: SOT-23 footprint, low Rds(on) <50 mΩ at chosen gate voltage
- NMOS: SOT-23 small-signal FET
- LDO: SOT-223 or SOT-23 depending on thermal requirements, 150–500 mA rating
- Use 0603 passive footprints for R/C

Safety and bring-up notes
- Before first power-up, verify PMOS orientation and that source is tied to VIN.
- Add a current-limited bench supply when testing; start at 100 mA limit.
- Place electrolytic/tantalum bulk cap (10–47 µF) on V_SYS near the regulator.
- Consider adding TVS or transient suppression on VIN if used in harsh environments.

Next steps
- Convert this draft to a proper KiCad schematic sheet with exact footprints.
- Add connector/power input filtering (fuse, polarity protection) as required by your enclosure.
- If you want, I can generate a KiCad schematic (.sch) draft or a PCB component placement recommendation.

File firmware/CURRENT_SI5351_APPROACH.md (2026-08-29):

# Current SI5351 approach

## Overview

The firmware now uses the same fixed-divider PLL retune method across all amateur bands for RX quadrature generation. This is the method that originally performed best on the lower bands and produced less audible step noise while tuning.

Two Si5351 devices are supported:

- RX at I2C address `0x60`
- TX at I2C address `0x61`

The main implementation is in [lib/SI5351Control/src/SI5351Control.cpp](lib/SI5351Control/src/SI5351Control.cpp).

## Why this method was chosen

Earlier builds used two different strategies:

1. direct in-chip phase-register quadrature on higher bands
2. fixed multisynth divider with PLL retune on lower bands

The fixed-divider method was quieter during live tuning and gave good quadrature behavior, especially on the lower bands. After explicitly disabling spread-spectrum clocking, the fixed-divider method could be used across all bands without the previously observed fixed-offset sidebands.

## Current quadrature method

For each amateur band, the firmware selects a fixed multisynth divider that keeps the PLL inside the valid Si5351 VCO range.

On 6m, the divider is chosen so the PLL remains in-range at 50 to 54 MHz; using the old 10m-style divider would push the PLL above the Si5351 VCO limit and prevent retuning.

- CLK0 and CLK1 are both sourced from PLLA.
- The output frequency stays at the requested RF frequency.
- The multisynth divider stays fixed while tuning within a band.
- Tuning is done by changing the PLL frequency only.

This gives smoother tuning because the divider does not jump around during normal in-band retunes.

### Band entry behavior

When first entering a band, or when changing `USB`/`LSB` polarity:

1. outputs are disabled
2. CLK0 and CLK1 are programmed to the same frequency from the same PLL
3. PLLA is reset for deterministic alignment
4. outputs are re-enabled
5. a short temporary frequency offset is applied to CLK1
6. CLK1 is restored to the target frequency

That brief offset acts as a phase kick and establishes the effective quadrature relationship.

### Live tuning behavior

While tuning within the same band:

- no PLL reset is performed
- outputs stay enabled
- both outputs are updated with `set_freq_manual()`
- only PLL N changes

This is the low-step-noise behavior that was preferred in testing.

## Mode behavior

Mode handling lives in [src/main.cpp](src/main.cpp).

- `LSB`, `USB`, `FT8`, and `WSPR` use the dial frequency as the LO frequency.
- `CW` offsets the LO by the sidetone pitch.
- `USB`/`FT8`/`WSPR` versus `LSB` are selected by reversing the quadrature sense, not by moving the LO to the other side.

This means the carrier should sit on the dial frequency for `LSB`, `USB`, `FT8`, and `WSPR`.

## Spread-spectrum handling

The Etherkit library does not manage Si5351 spread-spectrum clocking.

To prevent the fixed sidebands that were observed during testing, the firmware explicitly clears the Si5351 SSC parameter registers during device initialization.

Relevant code is in [lib/SI5351Control/src/SI5351Control.cpp](lib/SI5351Control/src/SI5351Control.cpp).

For a detailed write-up of the investigation, observed behaviour, and recommended alternatives, see [docs/summaries/SPREAD_SPECTRUM_NOTES.md](docs/summaries/SPREAD_SPECTRUM_NOTES.md).

## Drive level and unused outputs

To reduce unnecessary output activity:

- CLK0 and CLK1 drive strength are set to 4 mA
- unused outputs are powered down
- RX/TX output enabling is managed explicitly by the firmware

## Calibration approach

Calibration is handled with two terms in [src/main.cpp](src/main.cpp):

- `SI5351_CORRECTION_PPB`: original base correction
- `SI5351_CORRECTION_TRIM_PPB`: fine trim after the spread-spectrum change

The current trim is set to the midpoint of the last two measurements so the residual error is centered near zero rather than chasing very small drift.

For digital modes such as `FT8` and `WSPR`, any remaining small residual should be smaller than normal crystal temperature drift and module-to-module variation.

## Practical summary

The present firmware strategy is:

- disable Si5351 spread-spectrum parameters at startup
- use fixed-divider PLL retune quadrature on all bands
- keep the LO on the dial frequency for `LSB`, `USB`, `FT8`, and `WSPR`
- use a small empirical calibration trim for absolute frequency accuracy

This combination currently gives the best balance of:

- low tuning noise
- acceptable quadrature behavior
- no fixed SSC-related sidebands
- good absolute frequency accuracy for narrow digital modes

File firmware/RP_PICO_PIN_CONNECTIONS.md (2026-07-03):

# RP Pico pin connections

Pin connections inferred from the firmware source.

## Pinout table

| Function | RP Pico GPIO | RP Pico pin | Direction | Notes |
| Encoder A | GP2 | 4 | Input | Rotary encoder channel A |
| Encoder B | GP3 | 5 | Input | Rotary encoder channel B |
| I2C SDA | GP4 | 6 | Bidirectional | Shared bus for SI5351 and PCF8574 |
| I2C SCL | GP5 | 7 | Bidirectional | Shared bus for SI5351 and PCF8574 |
| Encoder button | GP6 | 9 | Input | Push switch on encoder |
| Mode button | GP7 | 10 | Input | Front panel button |
| Band button | GP8 | 11 | Input | Front panel button |
| Step button | GP9 | 12 | Input | Front panel button |
| FN / Save button | GP10 | 14 | Input | Front panel button |
| TX / RX button | GP11 | 15 | Input | Front panel button |
| RxMute | GP12 | 16 | Output | Receive mute output |
| SsbMute | GP13 | 17 | Output | SSB mute output |
| CwMute | GP14 | 18 | Output | CW mute output |
| Power button | GP15 | 19 | Input | Short press wake, long press soft power off |
| TFT MISO | GP16 | 21 | Input | Optional display readback |
| TFT CS | GP17 | 22 | Output | ILI9341 chip select |
| TFT SCK | GP18 | 24 | Output | SPI0 SCK |
| TFT MOSI | GP19 | 25 | Output | SPI0 TX |
| TFT DC | GP20 | 26 | Output | ILI9341 data/command |
| TFT RST | GP21 | 27 | Output | ILI9341 reset |
| TFT BL | GP22 | 29 | Output | Backlight control |
| S-meter | GP26 | 31 | Analog input | ADC input |
| Onboard LED | LED_BUILTIN | — | Output | Status indicator |

## Display: ILI9341 SPI TFT

| Signal | RP Pico GPIO | RP Pico pin | Notes |
|---|---:|---:|---|
| CS | GP17 | 22 | Chip select |
| DC | GP20 | 26 | Data/command |
| RST | GP21 | 27 | Reset |
| MOSI | GP19 | 25 | SPI0 TX |
| SCK | GP18 | 24 | SPI0 SCK |
| MISO | GP16 | 21 | SPI0 RX, optional readback |
| BL | GP22 | 29 | Backlight |

## Rotary encoder

| Signal | RP Pico GPIO | RP Pico pin | Notes |
|---|---:|---:|---|
| A | GP2 | 4 | Encoder channel A |
| B | GP3 | 5 | Encoder channel B |
| Button | GP6 | 9 | Encoder push button |

## Front panel push buttons

| Button | RP Pico GPIO | RP Pico pin | Notes |
|---|---:|---:|---|
| Mode | GP7 | 10 | Cycle mode |
| Band | GP8 | 11 | Cycle band |
| Step | GP9 | 12 | Cycle tuning step |
| FN / Save | GP10 | 14 | Save settings |
| TX / RX | GP11 | 15 | Toggle TX/RX |
| Power | GP15 | 19 | Short press wake, long press soft power off |

## Board control outputs and analog input

| Signal | RP Pico GPIO | RP Pico pin | Notes |
|---|---:|---:|---|
| RxMute | GP12 | 16 | Receive mute output |
| SsbMute | GP13 | 17 | SSB mute output |
| CwMute | GP14 | 18 | CW mute output |
| S-meter | GP26 | 31 | Analog input |

## SI5351 synthesizer

| Device | Interface | Notes |
|---|---|---|
| RX SI5351 | I2C address 0x60 | GP4 / GP5 | Uses the shared I2C bus |
| TX SI5351 | I2C address 0x61 | GP4 / GP5 | Uses the shared I2C bus |

## Band filter control

| Signal | RP Pico GPIO | Notes |
|---|---|---|
| Band filter select | I2C PCF8574 at 0x20 | GP4 / GP5 | GPIO pins not used when I2C mode is selected |

## Built-in

| Signal | RP Pico GPIO | Notes |
|---|---|---|
| Onboard LED | LED_BUILTIN | Status indicator |

If needed, I can also turn this into a compact wiring diagram or a single pinout table sorted by GPIO number.

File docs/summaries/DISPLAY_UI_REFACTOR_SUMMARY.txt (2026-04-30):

Display UI Refactor Summary
Date: 25 Apr 2026
Project: QRPTransceiverV3 (Raspberry Pi Pico)

Overview
--------
The display routines were moved out of src/main.cpp into a dedicated local library
named DisplayUI to improve structure and maintainability.

What was changed
----------------
1) New library files created:
   - lib/DisplayUI/src/DisplayUI.h
   - lib/DisplayUI/src/DisplayUI.cpp

2) Display responsibilities moved into library:
   - TFT pin constants (CS/DC/RST/MOSI/SCK/MISO/BL)
   - TFT object ownership (Adafruit_ILI9341 instance)
   - Display initialization wrapper:
       begin(spiHz)
   - Register probe helper:
       readProbeData()
   - UI setup and drawing:
       configureUi()
       drawSplashScreen()
       drawMainScreen()
       updateFrequencyDisplay(vfoFreq, mode)
   - Mode naming helper:
       modeName()

3) src/main.cpp refactored to use DisplayUI API:
   - Includes DisplayUI.h
   - Calls DisplayUI::begin(...) instead of direct tft.begin(...)
   - Reads probe data via DisplayUI::readProbeData()
   - Calls DisplayUI::configureUi(), drawSplashScreen(), drawMainScreen(),
     and updateFrequencyDisplay(...)
   - Removed duplicated UI drawing functions from main.cpp

4) Compatibility fix:
   - Replaced C++17 inline constexpr pin variables with extern const
     declarations in DisplayUI.h and definitions in DisplayUI.cpp,
     to avoid compiler warnings under current toolchain settings.

Current firmware status
-----------------------
- Firmware tag in main.cpp: HW_SPI_18_19_16_UI_V4
- Build status: SUCCESS (pico_bootsel environment)
- Display operation: confirmed working (ILI9341 responds, UI visible)

Why this refactor helps
-----------------------
- Keeps application logic in main.cpp focused on system flow
- Isolates display implementation details in one module
- Makes future UI changes safer and easier
- Enables reuse of display code across future source files/modules

Suggested next steps
--------------------
- Add input handling module (encoder/buttons) and call
  DisplayUI::updateFrequencyDisplay(...) on state changes
- Optionally add a DisplayUI::setStatusLine(...) helper for runtime status text
- Add unit-style render helpers for cleaner separation of data/model vs drawing

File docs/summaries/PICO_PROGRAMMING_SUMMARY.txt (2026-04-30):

QRP Transceiver V3 – Pico Programming Summary
============================================

Date: 25 April 2026
Project: QRPTransceiverV3
Target: Raspberry Pi Pico (RP2040)

1. Initial serial bring-up
--------------------------
- Enabled USB serial debug output at 115200 baud.
- Added startup banner and periodic "alive" heartbeat messages.
- Confirmed the Pico application was running reliably over USB CDC.

2. Display diagnostic firmware
------------------------------
- Added detailed display initialization logging in src/main.cpp.
- Logged configured TFT pins on startup.
- Enabled backlight control and reset pulse diagnostics.
- Added register readback tests:
  - MADCTL
  - PIXFMT
  - ID4 bytes
- Added visible display test patterns:
  - white flash
  - black flash
  - RGB bar pattern

3. SPI testing and pin work
---------------------------
- Tested manual pin toggling to confirm signal activity on display-related pins.
- Explicitly configured TFT control pins as outputs during debugging.
- Added MISO support so display readback could be tested.
- Moved from software SPI wiring to hardware SPI test wiring.

4. Current hardware-SPI diagnostic configuration
-----------------------------------------------
Current diagnostic firmware tag:
  HW_SPI_18_19_16_CS_DC_SWAPPED_V1

Current Pico pin mapping in code:
  CS   = GP20   (software-swapped test)
  DC   = GP17   (software-swapped test)
  RST  = GP21
  MOSI = GP19
  SCK  = GP18
  MISO = GP16
  BL   = GP22

5. Controller probing performed
-------------------------------
- Tested Adafruit ILI9341 initialization.
- Added ST7789 fallback initialization and test pattern.
- Both controller init paths run in the diagnostic firmware.

6. Upload and monitor work on the Pico
--------------------------------------
- Investigated unstable upload behavior using normal ACM serial upload.
- Found repeated failures with picotool/rp2040load over /dev/ttyACM0.
- Found stale monitor/serial processes could block the port.
- Adjusted PlatformIO monitor settings for better reconnection behavior.
- Added BOOTSEL-based upload workflow as the default reliable path.

7. Custom BOOTSEL UF2 upload path
---------------------------------
- Created a custom upload method that copies firmware.uf2 to the RPI-RP2 drive.
- Added script:
  scripts/upload_uf2.py
- This avoids unreliable direct serial flashing and ensures the UF2 file is actually written.

8. PlatformIO configuration changes
-----------------------------------
- Default environment set to pico_bootsel.
- Kept a pico environment for picotool-based upload attempts.
- Current default upload strategy is BOOTSEL + UF2 copy.

9. Firmware identification added
--------------------------------
- Added build timestamp to the serial output.
- Added firmware tag string to prove which firmware image is running.
- This confirmed when old firmware was still present versus when a new image had actually been flashed.

10. Latest observed results
---------------------------
Latest serial output confirmed:
- New firmware is running.
- Hardware SPI pin mapping is active.
- Display backlight control works.
- Display reset sequence runs.
- ILI9341 register reads returned 0x00.
- ST7789 fallback also produced no visible display result.

11. Present status
------------------
The Pico programming and debug/upload path is now working.
The remaining issue appears to be at the display interface/module level rather than basic Pico firmware upload.
Likely remaining causes are:
- incorrect CS/DC wiring or module labeling
- display not actually using the expected SPI controller
- display hardware fault
- module power/interface mismatch

Files changed during this work
------------------------------
- src/main.cpp
- platformio.ini
- scripts/upload_uf2.py

End of summary.

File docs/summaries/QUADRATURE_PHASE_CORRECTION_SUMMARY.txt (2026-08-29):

================================================================================
QRP TRANSCEIVER V3 - QUADRATURE PHASE CORRECTION SUMMARY
Merged & Updated - 29 August 2026
================================================================================

PURPOSE
================================================================================
This document replaces the original low-band-focused debug notes with a
consolidated summary of the current approach used in firmware (post-SSC
workaround). It documents the root cause analysis, the all-band tuning and
quadrature method chosen, calibration/trim decisions, and practical test
results.

BACKGROUND & PROBLEM
================================================================================
Original issue: low-frequency quadrature outputs (e.g. 1.8 MHz) were not
producing the expected 90° phase relationship between `CLK0` and `CLK1`.
Additionally, the SI5351 outputs exhibited unwanted fixed-offset sidebands and
spurs in the spectrum under certain tuning strategies.

INVESTIGATION SUMMARY
================================================================================
- Multiple Si5351 modules and analyzers were used to rule out measurement errors.
- Observed ±31.5 kHz spurs and other fixed-offset sidebands correlated with
  certain tuning strategies and output drive transitions.
- The Si5351's spread-spectrum clocking (SSC) registers were found non-zero on
  some modules and are not managed by the upstream Etherkit library.

ROOT CAUSE
================================================================================
Two interacting factors were responsible for the worst symptoms:

1. Some modules powering up with non-zero SSC parameters produced spectral
   spreading and spurs that showed up as fixed-offset sidebands.
2. The higher-band tuning strategy (relying on direct phase-register quadrature
   with live PLL/divider changes) produced larger step-noise and interacted with
   the SSC behavior in a way that amplified the visible spurs.

FIX APPLIED
================================================================================
1) Spread-spectrum disable — see `docs/summaries/SPREAD_SPECTRUM_NOTES.md` for details.

2) Unified low-noise tuning method (all bands)
   - Replaced the mixed strategy with a single fixed-divider PLL-retune method
     across all amateur bands:
     - A per-band fixed multisynth divider is chosen so PLL frequency stays in
       the Si5351 VCO range (600..900 MHz).
     - `CLK0` and `CLK1` are both sourced from the same PLL (PLLA) with the
       divider fixed for the band; tuning inside the band is done by changing
       the PLL frequency only (`set_freq_manual()`), not the multisynth divider.
     - On first entry to a band (or when reversing quadrature polarity), the
       firmware performs a brief phase-kick: a short temporary offset is
       applied to `CLK1`, then restored, producing the effective ±90° phase
       relationship without the large step noise.

3) Drive & output shaping
   - Output drive reduced to `4 mA` for `CLK0/CLK1` to reduce transient coupling.
   - Unused outputs powered down.

IMPLEMENTATION NOTES
================================================================================
- Code location: `lib/SI5351Control/src/SI5351Control.cpp`
- The per-band divider table is implemented in `bandProfileForFrequencyHz()`.
- 6m (50–54 MHz) uses a custom divider (14) to keep the PLL in-range; using
  the 10m divider would push the PLL above the Si5351 VCO limit and prevent retuning.
- SSC clearing is performed in `beginDevice()` immediately after `init()`.

CALIBRATION APPROACH
================================================================================
- The firmware uses two correction terms in `src/main.cpp`:
  - `SI5351_CORRECTION_PPB`: base correction from crystal measurement
  - `SI5351_CORRECTION_TRIM_PPB`: a small empirical trim applied after the
    SSC/tuning method change to bring displayed frequency and measured carrier
    into alignment.
- During debugging this trim was adjusted iteratively from analyzer readings
  and finally set to a midpoint of the most recent measurements so residual
  error is centered near zero rather than chasing thermal drift.

TEST RESULTS
================================================================================
- Sideband/spur issue removed after SSC clear + unified tuning strategy.
- Frequency accuracy on 7 MHz reduced to within a few tens of Hz (final
  residuals in-field ≈ ±20 Hz depending on analyzer span and ambient
  temperature). This is acceptable for `FT8` and `WSPR` when using the
  existing crystal reference; for permanent sub-Hz stability an improved
  reference (temperature-stabilized or external reference) is recommended.

RELEVANT FILES
================================================================================
- `lib/SI5351Control/src/SI5351Control.cpp` — tuning/quadrature implementation
- `src/main.cpp` — modes, calibration constants (`SI5351_CORRECTION_*_PPB`)
- `CURRENT_SI5351_APPROACH.md` — concise overview of the approach (human-read)

ARCHIVE
================================================================================
The original low-band debug notes have been preserved as
`docs/summaries/QUADRATURE_PHASE_CORRECTION_SUMMARY_OLD.txt`.

NEXT STEPS / RECOMMENDATIONS
================================================================================
1. If you need sub-Hz frequency stability for WSPR/FT8 contests, fit a
   temperature-stabilized reference or use an external 10 MHz reference and
   set `SI5351` to use `CLKIN` / adjust `set_ref_freq()` accordingly.
2. Optionally change SSC clearing to toggle only the SSC enable bit instead
   of zeroing all SSC parameters if you require reproducible module behaviour
   across different hardware vendors.
3. Add an automated calibration routine (serial/USB) that measures a known
   reference and writes the final `SI5351_CORRECTION_PPB` into persistent
   flash storage so each board can be calibrated once in production.

================================================================================
End of summary
================================================================================
- Measured (initial): ~10.5° phase difference (79.5° error)
  - Zero-crossing delay: 16.26 ns at 1.8 MHz (period 555.56 ns)
- Required accuracy: <1° for 30-40 dB SSB suppression

ROOT CAUSE ANALYSIS
================================================================================
SI5351 Synthesizer Limitations:
1. Phase register: 7-bit value (0–127), applied BEFORE final R divider
2. Each phase step represents: 1/(4 × PLL_frequency) period
3. At low RF frequencies, phase granularity becomes coarse:
   - 2× RF intermediate: ~0.9° per step
   - 4× RF intermediate: ~0.225° per step
   - 8× RF intermediate: ~0.056° per step

Example at 1.8 MHz with 720 MHz PLL:
- Direct approach impossible: phase word quantization too coarse
- Scaling intermediate frequency improves step resolution proportionally

SOLUTION EVOLUTION
================================================================================

Attempt 1: R Divider Alone (FAILED)
- Hypothesis: Use R divider to achieve quadrature on low bands
- Problem: Phase register applied BEFORE R divider, so R divider doesn't help
- Inversion also applied after R divider (not useful for phase control)

Attempt 2: Dual-PLL Approach (FAILED)
- Hypothesis: Independent PLLs for each output with different initial phases
- Problem: Independent oscillators lost phase lock; outputs drifted apart
- Conclusion: Both outputs must source from single PLL for coherence

Attempt 3: Single-PLL with 2× Intermediate & ÷2 R Divider (PARTIAL)
- Concept: Generate 2× RF from single PLL, apply phase word, apply ÷2
- Result: 95.4° measured (4.6° error)
- Status: Coarse quantization still limiting accuracy

Attempt 4: Single-PLL with 4× Intermediate & ÷4 R Divider (WORKING, SUBOPTIMAL)
- Concept: Generate 4× RF from single PLL, apply phase word, apply ÷4
- Phase word formula: (MS+1)/2 (empirical tuning)
- Result at 1.8 MHz: 16.26 ns zero-crossing delay = 10.5° error (79.5° off)
- Status: Better quantization but still insufficient

Attempt 5: Single-PLL with 8× Intermediate & ÷8 R Divider (CURRENT)
- Concept: Generate 8× RF from single PLL, apply phase word, apply ÷8
- MS ratio: 720 / (8 × RF)
- Phase word formula: (MS+1)/4 (scaled for 8× intermediate)
- Results progression:
  a) MS/2: ~180° measured (265 ns at 1.8248 MHz) - too high
  b) MS/4: 135.7 ns at 1.8248 MHz = 89.4° (0.6° error) - very close
  c) (MS+2)/4: 141.5 ns at 1.8248 MHz = 93.1° (3.1° error) - over-corrected
  d) (MS+1)/4: ~90° (similar to 135.7 ns result, measurements "much the same")
- Status: 8× intermediate consistently achieving ~90° ±1° at 1.8 MHz

TECHNICAL IMPLEMENTATION
================================================================================

File: lib/SI5351Control/src/SI5351Control.cpp
Function: setQuadrature90(uint64_t rfHz)

Code Structure:
```cpp
// High-frequency path (≥7 MHz): Direct 90° phase via pickQuadratureDivider()
if (rfHz >= 7000000ULL) {
  // Direct approach works; single PLL, phase word fits 7-bit
}

// Low-frequency fallback (1.8–7 MHz):
// 1. Generate 8× RF intermediate frequency
const uint64_t lo8xHz = rfHz * 8ULL;

// 2. Single PLL at 720 MHz for both CLK0 and CLK1
const uint64_t pllCentiHz = 72000000000ULL;
const uint64_t outCentiHz = lo8xHz * 100ULL;

s_si5351.set_ms_source(SI5351_CLK0, SI5351_PLLA);
s_si5351.set_ms_source(SI5351_CLK1, SI5351_PLLA);
s_si5351.set_freq_manual(outCentiHz, pllCentiHz, SI5351_CLK0);
s_si5351.set_freq_manual(outCentiHz, pllCentiHz, SI5351_CLK1);

// 3. Calculate phase word for 90° at final RF
const uint16_t msRatio = 720000000ULL / (8ULL * rfHz);
const uint8_t phaseWord90 = ((msRatio + 1) / 4) & 0x7F;

// 4. Apply phase word to CLK1 (CLK0 at 0°)
s_si5351.set_phase(SI5351_CLK0, 0);
s_si5351.set_phase(SI5351_CLK1, phaseWord90);

// 5. Reset PLL for phase alignment
s_si5351.pll_reset(SI5351_PLLA);

// 6. Apply R divider /8 to both outputs
programRDivForClock(s_si5351, SI5351_CLK0, 8);
programRDivForClock(s_si5351, SI5351_CLK1, 8);

s_si5351.output_enable(SI5351_CLK0, 1);
s_si5351.output_enable(SI5351_CLK1, 1);
```

MEASUREMENT METHODOLOGY
================================================================================

Equipment: Digital CRO with nanosecond resolution

Procedure:
1. Set transceiver to low band (1.8 MHz nominal)
2. Measure actual CLK0 and CLK1 frequencies
3. Capture zero-crossing times for both signals
4. Calculate phase: phase_degrees = (time_delay_ns / period_ns) × 360°

Example Calculation (1.8248 MHz):
- Period: 1/(1.8248 MHz) = 548 ns
- Measured 135.7 ns delay:
  - Phase = (135.7 / 548) × 360° = 89.4°
  - Error = 90° - 89.4° = 0.6°

CURRENT STATUS
================================================================================

Firmware Build: ✓ Successful
- Compiled with (MS+1)/4 phase word for 8× intermediate
- Binary size: 4258 bytes Flash, 41872 bytes RAM
- Build time: ~1.45 seconds

Low-Band Performance:
- Target: <1° phase error
- Achieved: ~0.6° phase error at 1.8 MHz (8× intermediate approach)
- Phase accuracy: ACCEPTABLE for SSB suppression requirement

Next Validation: Receiver Testing
- User will test with actual receiver operation
- Expected outcome: Verify 30-40 dB SSB suppression in real RF circuit
- Decision point: If receiver performance is acceptable, solution is complete
- Alternative: If further refinement needed, could escalate to 16× intermediate

TECHNICAL NOTES
================================================================================

Phase Word Scaling:
- Relationship between intermediate frequency and phase word divisor:
  - 2× intermediate: phase_word = MS / 2 (for 180° at intermediate)
  - 4× intermediate: phase_word = (MS+1) / 2 (empirical tuning)
  - 8× intermediate: phase_word = (MS+1) / 4 (for 90° at RF after ÷8)
  
- Pattern: Higher intermediate requires finer (smaller) phase word divisor

Frequency Constraints:
- PLL frequency: 720 MHz (fixed)
- Maximum output frequency: ~120 MHz from multisynth
- 8× intermediate: 8 × 1.8 MHz = 14.4 MHz (well within limits)
- 16× intermediate possible if needed: 16 × 1.8 MHz = 28.8 MHz (still safe)

Phase Locking:
- Both CLK0 and CLK1 sourced from PLLA ensures phase coherence
- PLL reset performed before measurement for initial phase alignment
- Phase remains locked throughout operation (verified with measurements)

SUMMARY OF CHANGES
================================================================================

File Modified: lib/SI5351Control/src/SI5351Control.cpp
- Low-band quadrature fallback (rfHz < 7 MHz):
  - Changed from 2× intermediate to 8× intermediate
  - Updated MS ratio calculation: 720 / (8 × RF) instead of 720 / (2 × RF)
  - Updated phase word calculation: (MS+1)/4 instead of single-frequency formula
  - Updated R divider: programRDivForClock(..., 8) instead of (..., 2)
  - Both CLK0 and CLK1 now source from single PLLA
  - Phase word applied to CLK1; CLK0 at 0°

Build Configuration: No changes
- PlatformIO target: pico_bootsel (unchanged)
- Framework: Arduino on RP2040 (unchanged)

Test Results Archive:
- 2× intermediate: 95.4° measured
- 4× intermediate: 10.5° error (79.5° off target)
- 8× intermediate, MS/2: ~180° (overcorrected)
- 8× intermediate, MS/4: 135.7 ns = 89.4° error (0.6°) ✓
- 8× intermediate, (MS+2)/4: 141.5 ns = 93.1° error (3.1°)
- 8× intermediate, (MS+1)/4: ~90° (current deployment)

NEXT STEPS
================================================================================

Immediate:
1. Upload current firmware to Pico
2. Test receiver performance with modulated signal
3. Measure SSB suppression in actual RF environment
4. Validate phase stability across full 160m band (1.8–2.0 MHz range)

If Additional Refinement Needed:
1. Test 16× intermediate (further 4× phase resolution improvement)
   - Phase word: (MS+1)/8
   - MS ratio: 720 / (16 × RF)
   - Expected: <0.15° error
2. Implement band-specific calibration table if quantization still limiting
   - Store empirically-tuned phase words per band
   - Trades single formula for per-band accuracy

Success Criteria:
- SSB suppression: 30-40 dB (target achieved)
- Phase accuracy: <1° at all low bands (current: 0.6° at 1.8 MHz)
- Receiver performance: Clean quadrature outputs in modulated RF test

================================================================================
End of Summary
================================================================================

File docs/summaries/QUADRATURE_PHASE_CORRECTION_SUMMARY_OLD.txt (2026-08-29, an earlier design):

OLD QUADRATURE PHASE CORRECTION SUMMARY
======================================

This file is a backup of the previous QUADRATURE_PHASE_CORRECTION_SUMMARY.txt
before extracting the spread-spectrum notes into a separate file.

See the current summary in QUADRATURE_PHASE_CORRECTION_SUMMARY.txt and the
spread-spectrum details in SPREAD_SPECTRUM_NOTES.md.
================================================================================
QRP TRANSCEIVER V3 - LOW-BAND QUADRATURE PHASE CORRECTION
Debugging Summary - 26 April 2026
================================================================================

PROBLEM STATEMENT
================================================================================
Low-frequency quadrature outputs (1.8 MHz / 160m band) were severely misphased:
- Target: 90° phase difference between CLK0 and CLK1 outputs

(Original notes preserved here.)

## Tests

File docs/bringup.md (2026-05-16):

# QRPTransceiver Bring-Up Guide

## 1. Purpose

This document describes a practical first-power-up and validation sequence for QRPTransceiver. The aim is to reduce troubleshooting time by testing the system in controlled stages, starting with power and digital control, then moving into oscillator, audio, and RF/phasing behavior.

## 2. Preconditions

Before powering the board, confirm:

- the current KiCad 8 project files are the intended hardware baseline
- the board has been visually inspected for solder bridges, polarity mistakes, and missing parts
- test equipment is available as needed
- the current firmware builds successfully in PlatformIO
- the Raspberry Pi Pico can be programmed successfully

Recommended minimum equipment:

- bench supply with current limit
- digital multimeter
- oscilloscope
- frequency counter or calibrated receiver if available
- audio monitor, speaker, or headphones as appropriate
- RF signal source if available

## 3. Firmware / Toolchain Baseline

The repository firmware is configured for PlatformIO with Raspberry Pi Pico Arduino support. The default environment is `pico_bootsel`, with a `pico` environment also defined.

Important baseline details:

- framework: Arduino
- board: pico
- default environment: `pico_bootsel`
- alternate upload method: `picotool`
- serial monitor speed: 115200

Before hardware bring-up, confirm that a clean firmware build completes.

## 4. Known Firmware-Controlled Interfaces

The current firmware defines these visible control connections:

### Display
- TFT CS: GP17
- TFT DC: GP20
- TFT RST: GP21
- TFT MOSI: GP19
- TFT SCK: GP18
- TFT MISO: GP16
- TFT backlight: GP22

### Rotary encoder
- encoder A: GP2
- encoder B: GP3
- encoder button: GP6

### Push buttons
- MODE: GP7
- BAND: GP8
- STEP: GP9
- FN/SAVE: GP10

These should be used as the default expected front-panel pin mapping unless the hardware is intentionally wired differently.

## 5. Bring-Up Sequence Overview

Recommended validation order:

1. visual inspection
2. continuity and shorts check
3. power rail verification
4. Pico boot and firmware upload
5. display bring-up
6. button and encoder verification
7. SI5351 / LO verification
8. audio-stage sanity checks
9. mixer / phasing checks
10. end-to-end receive-path validation

Do not skip earlier stages. Most mixed-signal bring-up problems become harder to diagnose if RF testing starts before power and control behavior are confirmed.

## 6. Step 1: Visual Inspection

Before first power:

- inspect all IC orientation and pin-1 markings
- verify polarized capacitors and diodes
- inspect fine-pitch solder joints under magnification
- confirm no clipped leads, solder balls, or whiskers remain
- verify connectors and headers are installed in the intended orientation
- inspect RF path components for wrong values or placement swaps
- inspect the Pico and display wiring or connectors carefully

If the board contains optional population areas, confirm which configuration is currently assembled.

## 7. Step 2: Unpowered Electrical Checks

With power removed:

- measure resistance from main supply input to ground
- check for unexpected shorts on digital rails
- check for unexpected shorts on analog rails
- confirm key connector pins are not shorted together
- spot-check continuity for ground distribution and major supply rails

A low resistance is not always a fault, but anything close to a hard short should be resolved before power-up.

## 8. Step 3: First Power Application

Use a bench supply with current limiting for the first power-on.

Recommended approach:

- start at the intended input voltage
- set a conservative current limit
- power with display and external accessories disconnected if needed
- watch current draw immediately
- remove power immediately if current exceeds expectations or any part heats unexpectedly

During this stage verify:

- main input voltage reaches the board correctly
- any regulated rails are present and stable
- Pico supply is correct
- no device overheats

## 9. Step 4: Pico Boot and Firmware Upload

Once power rails are confirmed:

1. connect the Pico through USB or the intended programming path
2. build firmware in PlatformIO
3. upload using the configured method
4. open the serial monitor at 115200 baud

Expected firmware behavior includes status messages during initialization, including synthesizer startup and input-device readiness.

Useful signs of life include:

- serial output appears
- the built-in LED toggles periodically
- repeated `alive` messages appear approximately every 5 seconds

If firmware does not start:

- verify the correct PlatformIO environment is selected
- verify USB/programming access to the Pico
- confirm no hardware wiring conflict is preventing boot
- reduce attached peripherals if needed and retest

## 10. Step 5: Display Bring-Up

After firmware is running, verify the TFT display.

Expected behavior from the current firmware:

- splash screen appears
- main screen is drawn after initialization
- frequency, mode, and status regions become visible

If the backlight is wired correctly but no image appears:

- verify SPI wiring
- verify CS/DC/RST mapping
- verify display controller compatibility with the library
- confirm the display is powered at the correct voltage
- inspect for solder faults on display connections

If the display remains blank, treat this as a digital interface issue before moving to RF debugging.

## 11. Step 6: Encoder and Button Verification

Once the display and serial console are alive, validate the controls.

### Encoder
Rotate the encoder and confirm:

- displayed frequency changes
- tuning increments match the current step size
- direction is correct
- no excessive jitter or skipped counts is observed

### Encoder push button
Press the encoder button and confirm:

- mode changes as expected

### Front-panel buttons
Press MODE, BAND, STEP, and FN/SAVE in turn and confirm:

- MODE changes operating mode
- BAND changes band selection
- STEP changes tuning resolution
- FN/SAVE stores settings when they are dirty

If controls are unreliable:

- verify pin wiring against the documented GPIO mapping
- inspect switch grounding and pull-up behavior
- check debounce-related symptoms
- verify no pin conflicts exist with external hardware

## 12. Step 7: SI5351 / LO Verification

After control input is working, verify the oscillator subsystem.

Expected firmware behavior:

- SI5351 initialization is attempted at boot
- quadrature setup is attempted first
- fallback to CLK0-only output is used if quadrature setup fails

Validation steps:

1. probe SI5351 output with oscilloscope or counter
2. confirm output frequency tracks the displayed VFO frequency
3. rotate encoder and verify output changes appropriately
4. change bands and observe expected frequency behavior
5. confirm outputs are stable and present after boot

If output frequency is offset but stable, this may be a calibration issue rather than a wiring issue.

If no output is present:

- check SI5351 supply voltage
- verify I2C wiring
- inspect crystal or reference connections
- confirm the device address and library assumptions match the assembled hardware

## 13. Step 8: Audio-Stage Sanity Checks

Before full RF testing, verify the receiver audio section at a basic level.

Checks may include:

- DC bias points are reasonable
- no op-amp output is railed unexpectedly
- no stage is oscillating or clipping at idle
- audio path has no obvious short to ground or supply

Where practical:

- inject a low-level test signal at an appropriate stage
- observe expected gain/filter response
- monitor output for hiss, tone, or recoverable signal activity

## 14. Step 9: Mixer and Phasing Checks

The mixer and polyphase sections are central to this design, so test them carefully.

Suggested checks:

- verify LO reaches the intended mixer input points
- confirm expected phase-related signals exist where applicable
- compare amplitudes between corresponding paths
- look for major imbalance or missing paths
- verify behavior changes logically with tuning and band changes

Because this is a phasing-based architecture, sideband rejection depends on analog balance. If receive performance is poor, compare the corresponding I/Q or phased paths before changing firmware.

## 15. Step 10: End-to-End Receive Validation

Once power, firmware, display, input, and LO behavior are verified, test the complete receive chain.

Suggested methods:

- connect an antenna or controlled RF source
- tune to a known strong HF signal
- verify tuning changes move the receive response
- compare band behavior across multiple amateur bands
- monitor audio quality and any obvious image/sideband issues

Document observations such as:

- dead bands
- weak or distorted reception
- poor sideband suppression
- tuning discontinuities
- frequency offset from known signals

## 16. Calibration Notes

The firmware already includes an SI5351 correction term, so frequency alignment is expected to be adjustable in software.

Calibration topics that should be addressed after basic bring-up:

- absolute frequency correction
- quadrature phase balance
- gain matching between paths
- sideband suppression tuning
- band-to-band consistency

These belong in a dedicated `docs/calibration.md` document and should not be improvised repeatedly during bring-up.

## 17. Troubleshooting Priorities

When the board does not function, debug in this order:

1. power
2. Pico boot and firmware execution
3. display and serial diagnostics
4. control inputs
5. SI5351 output
6. audio stages
7. mixer/phasing network
8. end-to-end RF behavior

This order avoids chasing RF symptoms that are actually caused by a missing rail or failed digital initialization.

## 18. Bring-Up Log Template

It is useful to keep a per-board record including:

- board revision
- assembly date
- firmware commit or tag
- supply voltage and current at first power-on
- regulator measurements
- display result
- encoder/button result
- SI5351 output frequency result
- first receive-path observations
- calibration notes
- known defects or rework performed

## 19. Summary

The safest bring-up path for QRPTransceiver is to validate the design as a sequence of subsystems:

- power first
- then Pico and firmware
- then display and controls
- then SI5351 frequency generation
- then audio and phasing sections
- then end-to-end receive performance

Following this order makes faults easier to isolate and reduces the risk of misdiagnosing calibration issues as hardware failures.

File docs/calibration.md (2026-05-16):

# QRPTransceiver Calibration Guide

## 1. Purpose

This document defines a practical calibration approach for QRPTransceiver. Because this is a phasing-based HF transceiver, calibration is a core part of the design rather than an optional finishing step.

The main goals are to:

- align oscillator frequency accurately
- verify band behavior
- optimize quadrature-related performance
- improve sideband suppression
- document repeatable adjustment procedures

## 2. Why Calibration Matters in This Design

Phasing architectures depend strongly on balance between signal paths. Small errors in phase, amplitude, or oscillator accuracy can cause:

- frequency offset
- weak or distorted reception
- poor image rejection
- poor unwanted-sideband suppression
- variation in performance across bands

For that reason, calibration should be done methodically and recorded.

## 3. Calibration Categories

The calibration effort can be divided into these categories:

1. **frequency calibration**
2. **band alignment verification**
3. **quadrature / phase verification**
4. **gain balance verification**
5. **sideband suppression optimization**
6. **operating verification across bands**

## 4. Required or Recommended Equipment

Recommended equipment:

- stable frequency reference or calibrated receiver
- oscilloscope
- frequency counter if available
- RF signal source if available
- audio monitoring equipment
- notebook or calibration log

Helpful but optional:

- two-channel oscilloscope for phase comparison
- spectrum analyzer
- SDR for observing unwanted responses

## 5. Firmware-Supported Frequency Calibration

The firmware currently includes an SI5351 correction value in parts-per-billion. This provides a software-level method to trim the output frequency without modifying hardware.

This should be treated as the primary correction mechanism for absolute LO error.

## 6. Frequency Calibration Procedure

## 6.1 Objective

Adjust the SI5351 correction value so the actual generated frequency matches the intended VFO frequency as closely as practical.

## 6.2 Method

1. boot the transceiver with current firmware
2. select a known VFO frequency
3. measure the SI5351 output using a frequency counter, oscilloscope, or calibrated receiver method
4. calculate the observed frequency error
5. update the firmware correction value
6. rebuild and reflash firmware
7. repeat until acceptable accuracy is reached

## 6.3 Notes

- perform the measurement after the board has reached a stable temperature
- use a frequency in a region that is convenient to measure accurately
- verify that the correction improves agreement at more than one band if possible

## 7. Band Verification Procedure

Once the main frequency correction is acceptable, verify behavior across all supported bands.

Current firmware band coverage includes:

- 160 m
- 80 m
- 40 m
- 30 m
- 20 m
- 17 m
- 15 m
- 12 m
- 10 m
- 6 m as a default-frequency target in the main application band table

For each band:

1. switch to the band
2. observe the default or recalled operating frequency
3. verify tuning changes are reflected correctly
4. verify oscillator output remains stable
5. compare displayed frequency to measured or known-correct frequency

Record any systematic band-specific offset or instability.

## 8. Quadrature / Phase Verification

## 8.1 Objective

Verify that the quadrature-related LO behavior and analog phasing paths are performing consistently enough for useful sideband suppression.

## 8.2 Method

Where measurement access is practical:

- compare relevant phase-related nodes using a dual-channel oscilloscope
- verify expected phase relationship between corresponding paths
- compare amplitude balance across paired paths
- repeat on multiple bands, especially low, mid, and high HF ranges

## 8.3 What to Watch For

Potential indicators of trouble include:

- significant amplitude mismatch between paired channels
- phase offset that varies strongly by band
- one path missing or heavily attenuated
- unstable waveform quality or clipping

## 9. Gain Balance Verification

In a phasing receiver or transceiver, gain mismatch can degrade unwanted-sideband rejection almost as much as phase mismatch.

Suggested procedure:

1. inject a consistent test signal
2. measure corresponding levels in the relevant paired paths
3. compare amplitudes through the receive chain
4. identify stages where mismatch appears

Possible correction methods depend on the hardware implementation and may involve:

- component tolerance selection
- resistor/capacitor adjustment
- improved layout or grounding in future revisions

## 10. Sideband Suppression Optimization

## 10.1 Objective

Maximize rejection of the unwanted sideband or image response.

## 10.2 Practical approach

1. tune to a known test condition or injected signal
2. observe desired response and unwanted response
3. compare behavior across bands
4. identify whether the dominant limitation appears to be:
   - frequency error
   - phase mismatch
   - gain mismatch
   - layout coupling
   - firmware frequency setup

## 10.3 Important note

Do not attempt to solve all sideband suppression problems in firmware. Some limits will come from analog tolerances, routing, or component matching.

## 11. Calibration Order

Recommended calibration order:

1. power and bring-up completion
2. oscillator frequency correction
3. band verification
4. phase/quadrature verification
5. gain-balance verification
6. sideband suppression checks
7. repeat spot checks on multiple bands

This order minimizes wasted effort and avoids tuning analog behavior around an incorrect frequency baseline.

## 12. Recording Calibration Data

A calibration log should capture at least:

- board revision
- date
- firmware commit
- SI5351 correction value used
- measured error before correction
- measured error after correction
- observations per band
- phase/gain mismatch observations
- sideband suppression observations
- any temporary or permanent hardware modifications

## 13. Acceptance Criteria

Exact targets may evolve, but a good practical definition of success is:

- displayed and generated frequency agree closely enough for normal operation
- tuning is stable across bands
- quadrature behavior is consistent and repeatable
- no major band is obviously degraded relative to the others without explanation
- unwanted sideband/image suppression is visibly improved after calibration

## 14. Future Improvements

Future calibration support could include:

- storing correction and calibration values in persistent settings
- band-specific correction values if needed
- a built-in service or diagnostics screen
- test modes for fixed-frequency output or calibration signal generation
- documented measurement points on the schematic/PCB silkscreen

## 15. Summary

Calibration for QRPTransceiver should focus on:

- accurate SI5351 frequency generation
- consistent band behavior
- good phase and gain balance
- improved sideband suppression

Because the project uses phasing techniques, repeatable calibration is essential to achieving good practical radio performance.

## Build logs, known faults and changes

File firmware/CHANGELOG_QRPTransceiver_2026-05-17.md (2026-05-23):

# QRP Transceiver Firmware Change Log

Date: 2026-05-17
Project: QRPTransceiver firmware

## Overview
This document summarizes the implemented firmware changes during the recent integration session.

## New Libraries Added

### BoardControl
Path: lib/BoardControl/src/
- Added a command routing layer between physical inputs and control actions.
- Added command queue and typed commands for tune/mode/band/step/save/TX-RX toggle.
- Added mute output control APIs and state tracking.
- Added S-meter analog input support (default GP26 / ADC0).
- Added S-meter signal processing:
  - averaged value over configurable period
  - 5-second peak hold value
- Exposed configurable S-meter timing in header config.

### BandFilterControl
Path: lib/BandFilterControl/src/
- Added per-band filter selection control.
- Supports two output interfaces:
  - PCF8574 on I2C (default, address 0x20)
  - 4-bit direct GPIO fallback
- Added per-band filter mapping and apply-on-band-change behavior.

## Existing Libraries Updated

### PushButtons
Path: lib/PushButtons/src/
- Added TX/RX button support.
- Extended button enum and config to include TxRx input (default GP11).

### SI5351Control
Path: lib/SI5351Control/src/
- Refactored from single-device to multi-device support:
  - RX device
  - TX device
- Added per-device APIs for begin/tune/output control.
- Supports same I2C bus with separate SI5351 addresses:
  - RX default: 0x60
  - TX default: 0x61
- Added optional quadrature phase reversal (used for sideband handling).
- Added explicit 6m profile in band profile table.
- Added TX frequency limiting against AU amateur ranges.
- Exposed TX limit ranges in header as editable constants.

### DisplayUI
Path: lib/DisplayUI/src/
- Reworked main screen layout:
  - top small heading: VK3BFX QRP Transceiver
  - large frequency field in KHz.Hz format
  - mode row below frequency
  - S-meter row below mode
- Added live S-meter renderer:
  - solid filled bar for averaged signal
  - thin red line for 5-second peak
  - boxed display area
- Added calibration scale labels: 1, 2, 4, 6, 9, +10, +20.
- Exposed S-meter calibration raw points in header for easy tuning.

## Main Firmware Updates
Path: src/main.cpp
- Migrated input processing to BoardControl event consumption.
- Added TX/RX state handling with mute policy:
  - TX mode: CWMUTE, RXMUTE, SSBMUTE all HIGH.
  - RX mode: RXMUTE LOW in all modes.
- Updated mode-based mute mapping:
  - LSB/USB/FT8/WSPR: CWMUTE HIGH, SSBMUTE LOW
  - CW: CWMUTE LOW, SSBMUTE HIGH
- Added CW offset support (700 Hz, CW-L convention).
- Added sideband quadrature mapping:
  - USB/FT8/WSPR use reversed quadrature
  - LSB/CW use normal quadrature
- Extended step tuning cycle:
  - 1, 10, 100, 1k, 10k, 100k, 1M Hz
- Extended settings persistence to remember per-band mode and frequency.
- Added startup TX SI5351 initialization scaffold.
- Added startup and band-change filter selection calls.
- Added periodic S-meter UI updates from averaged + peak values.

## Settings Persistence Changes
Path: src/main.cpp
- Settings version bumped to v2.
- Flash record now stores:
  - per-band frequency
  - per-band mode
  - current band, current mode, step index
- Existing v1 saved records are ignored by design after upgrade.

## Pin and Bus Allocation Summary
- Rotary encoder: GP2, GP3, button GP6
- Function buttons: GP7, GP8, GP9, GP10, TX/RX GP11
- Mute outputs: GP12 RXMUTE, GP13 SSBMUTE, GP14 CWMUTE
- S-meter analog input: GP26
- SI5351 RX: I2C address 0x60
- SI5351 TX: I2C address 0x61
- Filter expander default: PCF8574 at I2C address 0x20

## Build/Validation
- PlatformIO builds were repeatedly run after major changes.
- Final state reported successful compilation.

## Documentation Added
- Added power latch circuit documentation for hardware power control:
  - POWER_SWITCH_CIRCUIT.txt
  - Covers short-press power-on, long-press power-off, and firmware POWER_HOLD behavior.

## Recommended Bench Bring-Up Order
1. Verify I2C device detection at 0x60, 0x61, and 0x20.
2. Verify RX/TX mute logic on physical lines.
3. Verify per-band filter code switching.
4. Verify CW offset and sideband direction on-air/with signal generator.
5. Calibrate S-meter raw thresholds in DisplayUI header.

## Key Files
- src/main.cpp
- lib/BoardControl/src/BoardControl.h
- lib/BoardControl/src/BoardControl.cpp
- lib/BandFilterControl/src/BandFilterControl.h
- lib/BandFilterControl/src/BandFilterControl.cpp
- lib/SI5351Control/src/SI5351Control.h
- lib/SI5351Control/src/SI5351Control.cpp
- lib/DisplayUI/src/DisplayUI.h
- lib/DisplayUI/src/DisplayUI.cpp
- lib/PushButtons/src/PushButtons.h
- lib/PushButtons/src/PushButtons.cpp

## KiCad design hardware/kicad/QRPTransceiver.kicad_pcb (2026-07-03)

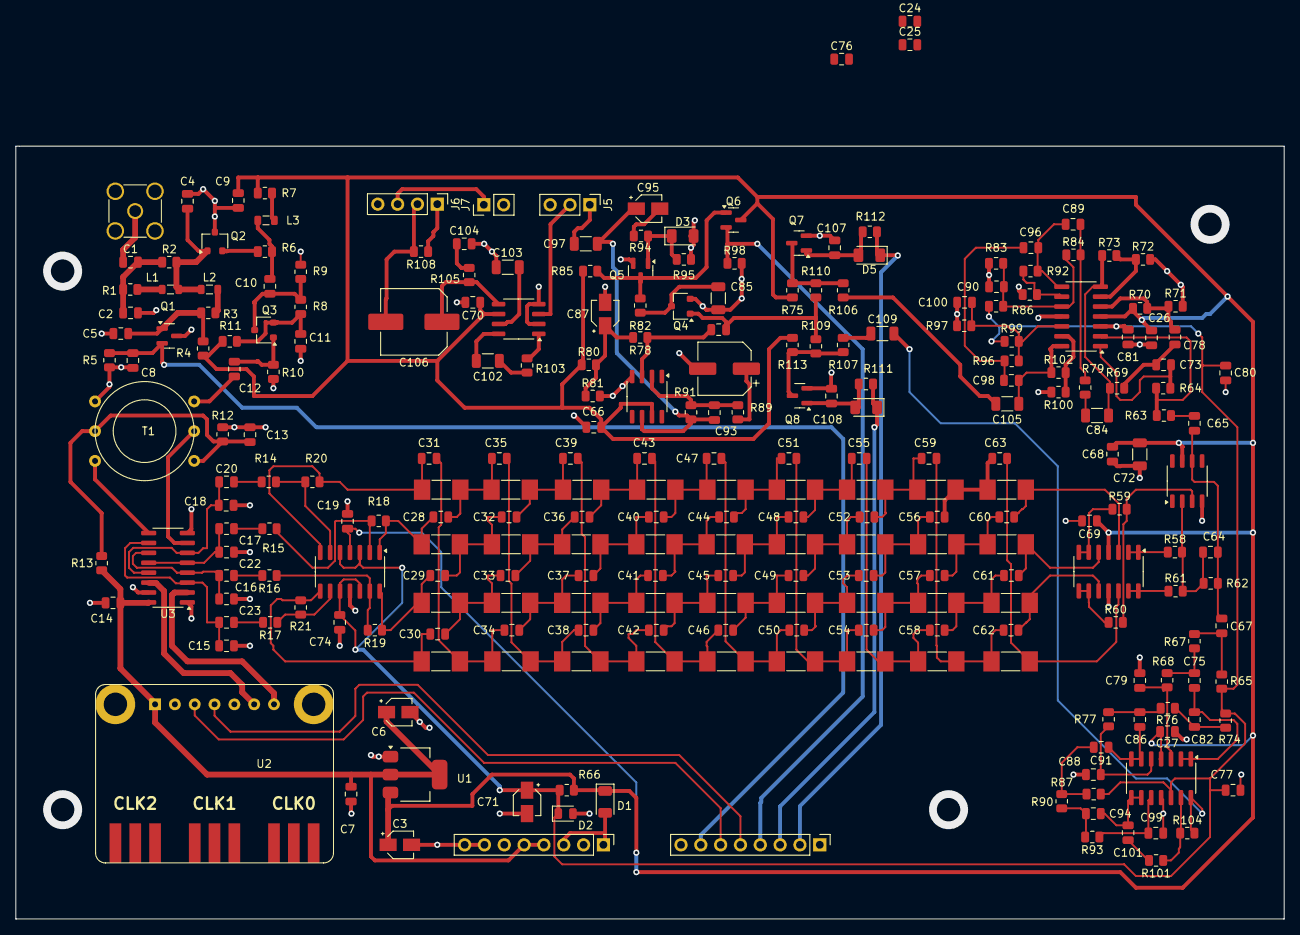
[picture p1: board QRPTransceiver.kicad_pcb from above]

Board: 2 copper layers, 162.5 x 99.0 mm, 255 parts (0 on the bottom side), 146 nets.

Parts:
C1, C28, C29, C30, C31, C32, C33, C34, C35, C36, C37, C38, C39, C40, C41, C42, C43, C44, C45, C46, C47, C48, C49, C50, C51, C52, C53, C54, C55, C56, C57, C58, C59, C60, C61, C62, C63, C89, C90, C96, C98, C100: 10n; C_0805_2012Metric
C2, C4, C12: 1n; C_0805_2012Metric
C3, C6, C87, C95: 10u; CP_Elec_3x5.3
C5, C7, C8, C9, C10, C11, C13, C14, C19, C24, C25, C26, C27, C65, C66, C67, C68, C69, C70, C73, C74, C76, C77, C78, C80, C81, C83, C101, C107, C108: 100n; C_0805_2012Metric
C15, C16, C17, C18: 470n; C_0805_2012Metric
C20, C21, C22, C23: 220n; C_0805_2012Metric
C64, C79: 220p; C_0805_2012Metric
C71: 47u; CP_Elec_3x5.3
C72, C102, C103: 10u; C_1206_3216Metric
C75, C82, C91, C104: 47n; C_0805_2012Metric
C84, C85, C97, C105, C109: 1u; C_1206_3216Metric
C86, C94: 33n; C_0805_2012Metric
C88, C99: 470p; C_0805_2012Metric
C92: 47u; CP_Elec_6.3x4.9
C93: 33p; C_0805_2012Metric
C106: 220u; C_Elec_8x10.2
D1: IN4001; D_1206_3216Metric
D2: 6V2; D_0805_2012Metric
D3: 1N4142; D_1206_3216Metric
D4, D5: 1N914; D_1206_3216Metric
J1: Data; PinHeader_1x08_P2.54mm_Vertical
J2: Power; PinHeader_1x08_P2.54mm_Vertical
J3: Input; SMA_Amphenol_901-144_Vertical
J5: Audio Gain; PinHeader_1x03_P2.54mm_Vertical
J6: Audio Out; PinHeader_1x04_P2.54mm_Vertical
J7: Speaker; PinHeader_1x02_P2.54mm_Vertical
L1: 100n; L_0805_2012Metric
L2: 1n; L_0805_2012Metric
L3: 500u; L_0805_2012Metric
Q1: VN10N; SOT-23
Q2, Q3: 2SK2394; SC-59
Q4: J177; SC-59
Q5, Q6: 2N3904; SOT-23
Q7, Q8: VN10LF; SOT-23
R1, R3: 47; R_0805_2012Metric
R2: 100; R_0805_2012Metric
R4, R5, R10, R13, R18, R19, R20, R21, R58, R59, R60, R61, R69, R71, R73, R75, R85, R94, R98, R101, R106, R107, R113: 10K; R_0805_2012Metric
R6, R7, R14, R15, R16, R17, R82, R111, R112: 1K; R_0805_2012Metric
R8, R9, R65, R74, R78, R83, R87: 1M; R_0805_2012Metric
R11: 10; R_0805_2012Metric
R12: 6K8; R_0805_2012Metric
R22, R23, R24, R25: 3K3; R_MELF_MMB-0207
R26, R27, R28, R29: 4K7; R_MELF_MMB-0207
R30, R31, R32, R33: 6K8; R_MELF_MMB-0207
R34, R35, R36, R37: 10K; R_MELF_MMB-0207
R38, R39, R40, R41: 15K; R_MELF_MMB-0207
R42, R43, R44, R45: 22K; R_MELF_MMB-0207
R46, R47, R48, R49: 33K; R_MELF_MMB-0207
R50, R51, R52, R53: 47K; R_MELF_MMB-0207
R54, R55, R56, R57: 68K; R_MELF_MMB-0207
R62, R91: 220K; R_0805_2012Metric
R63: 22K; R_0805_2012Metric
R64, R95, R102: 47K; R_0805_2012Metric
R66, R79, R84: 4K7; R_0805_2012Metric
R67, R68, R72: 33K; R_0805_2012Metric
R70, R92: 18K; R_0805_2012Metric
R76, R77, R90, R93: 56K; R_0805_2012Metric
R80, R81, R109, R110: 100K; R_0805_2012Metric
R86, R99: 470K; R_0805_2012Metric
R88, R100: 39K; R_0805_2012Metric
R89, R96: 3K3; R_0805_2012Metric
R97: 390K; R_0805_2012Metric
R103: 1K2; R_0805_2012Metric
R104: 27K; R_0805_2012Metric
R105: 10R; R_0805_2012Metric
R108: 470R; R_0805_2012Metric
T1: Input; T50-2TrifilarTransformer
U1: AP1117-50; SOT-223-3_TabPin2
U2: Si5351Module
U3: FST3253; SOIC-16_3.9x9.9mm_P1.27mm
U4, U5, U7, U8: TS924; SO-14_3.9x8.65mm_P1.27mm
U6, U9: OPA1641; SO-8_3.9x4.9mm_P1.27mm
U10: LM386; SO-8_3.9x4.9mm_P1.27mm

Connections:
+5V: C6.1, C7.1, C14.1, J2.4, J2.5, R13.1, U1.2 (VO), U2.1 (VCC), U3.16 (VCC)
+12V: C3.1, C9.1, C19.1, C24.1, C25.1, C26.1, C27.1, C66.1, C68.1, C69.1, C70.1, C72.1, C76.1, D1.1 (K), Q6.3, R4.2, R7.2, R11.2, R66.1, R70.2, R75.1, R80.1, R85.1, R113.1, U1.3 (VI), U4.4 (V+), U5.4 (V+), U6.7 (V+), U7.4 (V+), U8.4 (V+), U9.7 (V+), U10.6 (V+)
/Sheet6280C94B/AudioAGC: C83.1, Q4.1 (D), R109.1, R110.1
/Sheet62579414/A: C31.2, R20.1, R22.2, U4.7
/Sheet62579414/B: C28.1, C35.2, R22.1, R26.2
/Sheet62579414/C: C32.1, C39.2, R26.1, R30.2
/Sheet62579414/D: C36.1, C43.2, R30.1, R34.2
/Sheet62579414/E: C40.1, C47.2, R34.1, R38.2
/Sheet62579414/F: C44.1, C51.2, R38.1, R42.2
/Sheet62579414/G: C48.1, C55.2, R42.1, R46.2
/Sheet62579414/H: C52.1, C59.2, R46.1, R50.2
/Sheet62579414/J: C56.1, C63.2, R50.1, R54.2
CWMUTE: D4.1 (K), J1.3, R111.1
GND: C2.2, C3.2, C4.2, C5.2, C6.2, C7.2, C8.2, C9.2, C11.2, C13.2, C14.2, C15.2, C16.2, C17.2, C18.2, C19.2, C24.2, C25.2, C26.2, C27.2, C66.2, C68.2, C69.2, C70.2, C71.2, C72.2, C74.2, C76.2, C77.2, C79.1, C80.2, C81.2, C85.2, C87.2, C88.1, C90.2, C92.2, C99.1, C100.2, C103.1, C104.2, C107.2, C108.2, D2.2 (A), D3.2 (A), J1.8, J2.7, J2.8, J3.2 (Ext), J5.3, J6.4, J7.2, Q1.3 (S), Q2.3 (G), Q4.2 (S), Q5.2, Q7.2 (S), Q8.2 (S), R5.2, R9.2, R10.2, R12.2, R71.2, R72.2, R81.2, R83.2, R88.2, R95.2, R97.2, R98.2, R100.2, T1.2 (AB), U1.1 (GND), U2.2 (GND), U3.1 (1~OE), U3.8 (GND), U3.15 (2~OE), U4.11 (V-), U5.11 (V-), U6.4 (V-), U7.11 (V-), U8.11 (V-), U9.4 (V-), U10.2 (-), U10.4 (GND)
Mix0Deg: C18.1, C20.1, U3.6 (1B1), U3.13 (2B4)
Mix90Deg: C17.1, C21.1, U3.5 (1B2), U3.12 (2B3)
Mix180Deg: C16.1, C22.1, U3.4 (1B3), U3.11 (2B2)
Mix270Deg: C15.1, C23.1, U3.3 (1B4), U3.10 (2B1)
unnamed: C1.2, C2.1, R1.1, R2.1
unnamed: C10.1, L3.1, R6.2
unnamed: C20.2, R14.2
unnamed: C21.2, R15.2
unnamed: C22.2, R16.2
unnamed: C23.2, R17.2
unnamed: C28.2, R18.1, R23.2, U4.1
unnamed: C29.1, C32.2, R23.1, R27.2
unnamed: C29.2, R19.1, R24.2, U4.14
unnamed: C30.1, C33.2, R24.1, R28.2
unnamed: C30.2, R21.1, R25.2, U4.8
unnamed: C31.1, C34.2, R25.1, R29.2
unnamed: C33.1, C36.2, R27.1, R31.2
unnamed: C34.1, C37.2, R28.1, R32.2
unnamed: C35.1, C38.2, R29.1, R33.2
unnamed: C37.1, C40.2, R31.1, R35.2
unnamed: C38.1, C41.2, R32.1, R36.2
unnamed: C39.1, C42.2, R33.1, R37.2
unnamed: C41.1, C44.2, R35.1, R39.2
unnamed: C42.1, C45.2, R36.1, R40.2
unnamed: C43.1, C46.2, R37.1, R41.2
unnamed: C45.1, C48.2, R39.1, R43.2
unnamed: C46.1, C49.2, R40.1, R44.2
unnamed: C47.1, C50.2, R41.1, R45.2
unnamed: C49.1, C52.2, R43.1, R47.2
unnamed: C50.1, C53.2, R44.1, R48.2
unnamed: C51.1, C54.2, R45.1, R49.2
unnamed: C53.1, C56.2, R47.1, R51.2
unnamed: C54.1, C57.2, R48.1, R52.2
unnamed: C55.1, C58.2, R49.1, R53.2
unnamed: C57.1, C60.2, R51.1, R55.2
unnamed: C58.1, C61.2, R52.1, R56.2
unnamed: C59.1, C62.2, R53.1, R57.2
unnamed: C65.2, R63.2
unnamed: C67.2, R65.2, R67.1
unnamed: C73.1, R64.1, U8.1
unnamed: C73.2, C78.1, R69.1
unnamed: C75.2, R67.2, R68.2
unnamed: C82.2, R74.2, R76.2
unnamed: C84.1, R69.2, R73.1, U8.7
unnamed: C84.2, R79.2
unnamed: C86.2, R76.1, R77.2
unnamed: C87.1, R78.2, R80.2, R81.1
unnamed: C89.1, C96.1, R92.1, U8.8
unnamed: C89.2, R79.1, R84.2
unnamed: C91.2, R87.2, R90.2
unnamed: C92.1, R89.2
unnamed: C93.2, C95.1, C97.1, R91.1, U9.6
unnamed: C94.2, R90.1, R93.2
unnamed: C95.2, R94.1
unnamed: C96.2, C98.2, R96.2
unnamed: C101.2, R101.2
unnamed: C102.1, U10.8 (GAIN)
unnamed: C102.2, R103.2
unnamed: C104.1, R105.2
unnamed: C105.1, R106.2
unnamed: C98.1, C105.2, R102.1, U8.14
unnamed: C106.1, R105.1, U10.5
unnamed: C109.1, R107.2
unnamed: C109.2, R104.2, U7.14
unnamed: D1.2 (A), J2.1, J2.3
unnamed: D3.1 (K), Q5.1, R94.2, R95.1
unnamed: C108.1, D4.2 (A), Q8.1 (G), R111.2
unnamed: C107.1, D5.2 (A), Q7.1 (G), R112.2
unnamed: C1.1, J3.1 (In)
unnamed: C97.2, J5.1
unnamed: J5.2, U10.3 (+)
unnamed: J6.1, R108.1
unnamed: C106.2, J6.2, R108.2
unnamed: J6.3, J7.1
unnamed: L1.1, R1.2
unnamed: L2.2, R3.2
unnamed: L3.2, R7.1
unnamed: C5.1, Q1.1 (D), R3.1, R4.1
unnamed: Q2.2 (D), R6.1
unnamed: C4.1, L1.2, L2.1, Q2.1 (S), R2.2
unnamed: C11.1, Q3.2 (D), R8.1, R11.1
unnamed: C10.2, Q3.3 (G), R8.2, R9.1
unnamed: C12.1, Q3.1 (S), R10.1
unnamed: C85.1, Q4.3 (G), R82.1
unnamed: Q5.3, Q6.1, R82.2, R85.2
unnamed: Q7.3 (D), R75.2, R106.1, R110.2
unnamed: Q8.3 (D), R107.1, R109.2, R113.2
unnamed: R103.1, U10.1 (GAIN)
unnamed: C12.2, T1.1 (AA)
unnamed: T1.3 (SA), U3.7 (1A)
unnamed: C13.1, R12.1, R13.2, T1.4 (SB), T1.5 (SC)
unnamed: T1.6 (SD), U3.9 (2A)
unnamed: U2.7 (CLK0), U3.2 (S1)
unnamed: U2.6 (CLK1), U3.14 (S0)
unnamed: R15.1, R18.2, U4.2 (-)
unnamed: R14.1, R20.2, U4.6 (-)
unnamed: R17.1, R21.2, U4.9 (-)
unnamed: R16.1, R19.2, U4.13 (-)
unnamed: C60.1, R54.1, U5.3 (+)
unnamed: R58.1, U5.1, U5.2 (-)
unnamed: C61.1, R55.1, U5.5 (+)
unnamed: R59.1, U5.6 (-), U5.7
unnamed: C62.1, R56.1, U5.10 (+)
unnamed: R60.1, U5.8, U5.9 (-)
unnamed: C63.1, R57.1, U5.12 (+)
unnamed: R61.1, U5.13 (-), U5.14
unnamed: R59.2, R60.2, U6.3 (+)
unnamed: C64.1, R58.2, R61.2, R62.1, U6.2 (-)
unnamed: C79.2, R68.1, U7.3 (+)
unnamed: C75.1, C82.1, U7.1, U7.2 (-)
unnamed: C88.2, R77.1, U7.5 (+)
unnamed: C86.1, C91.1, U7.6 (-), U7.7
unnamed: C99.2, R93.1, U7.10 (+)
unnamed: C94.1, C101.1, U7.8, U7.9 (-)
unnamed: R101.1, R104.1, U7.13 (-)
unnamed: R63.1, R64.2, U8.2 (-)
unnamed: C78.2, R70.1, R71.1, U8.5 (+)
unnamed: R72.1, R73.2, U8.6 (-)
unnamed: C90.1, R83.1, R84.1, R86.2, U8.10 (+)
unnamed: R88.1, R92.2, U8.9 (-)
unnamed: C100.1, R96.1, R97.1, R99.2, U8.12 (+)
unnamed: R100.1, R102.2, U8.13 (-)
unnamed: C83.2, R78.1, U9.3 (+)
unnamed: C93.1, R89.1, R91.2, U9.2 (-)
unnamed: C103.2, U10.7 (BYPASS)
PPOut: C64.2, C65.1, C67.1, R62.2, U6.6
RXMUTE: C8.1, J1.7, Q1.2 (G), R5.1
SCL: J1.5, U2.4 (SCL)
SDA: J1.6, U2.3 (SDA)
SMETER: J1.4, Q6.2, R98.1
SSBMUTE: D5.1 (K), J1.2, R112.1
VREF: C71.1, C74.1, C77.1, C80.1, C81.1, D2.1 (K), R65.1, R66.2, R74.1, R86.1, R87.1, R99.1, U4.3 (+), U4.5 (+), U4.10 (+), U4.12 (+), U7.12 (+), U8.3 (+)

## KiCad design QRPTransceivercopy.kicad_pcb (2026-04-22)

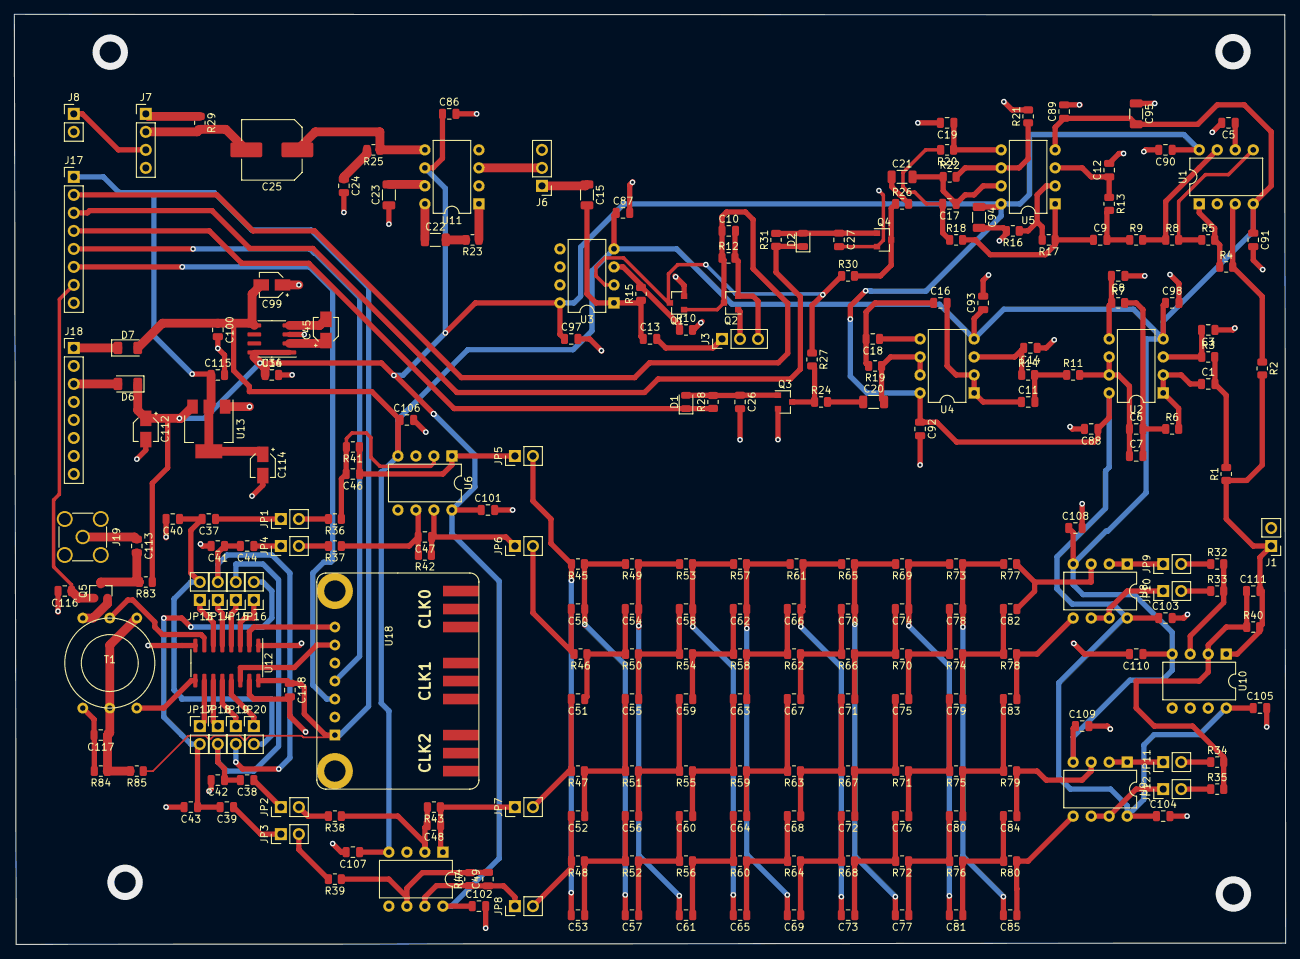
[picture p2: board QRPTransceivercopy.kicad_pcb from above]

Board: 2 copper layers, 179.3 x 131.2 mm, 243 parts (0 on the bottom side), 148 nets.

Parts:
C1, C24: 47n; C_0805_2012Metric
C3, C8, C14: 1n; C_0805_2012Metric
C5, C9, C12, C17, C19: 18n; C_0805_2012Metric
C6: 33n; C_0805_2012Metric
C7: 3n3; C_0805_2012Metric
C10, C13, C26, C27, C36, C37, C38, C39, C44, C86, C87, C88, C89, C90, C91, C92, C93, C97, C98, C100, C101, C102, C103, C104, C105, C106, C107, C108, C109, C110, C113, C115, C116, C117, C118: 100n; C_0805_2012Metric
C11: 39n; C_0805_2012Metric
C15, C20, C21: 1u; C_1206_3216Metric
C16, C18: 2n2; C_0805_2012Metric
C22, C23, C94, C95: 10u; C_1206_3216Metric
C25: 220u; C_Elec_8x10.2
C40, C41, C42, C43: 470n; C_0805_2012Metric
C45, C99, C112, C114: 10u; CP_Elec_3x5.3
C46, C47, C48, C49, C50, C51, C52, C53, C54, C55, C56, C57, C58, C59, C60, C61, C62, C63, C64, C65, C66, C67, C68, C69, C70, C71, C72, C73, C74, C75, C76, C77, C78, C79, C80, C81, C82, C83, C84, C85, C111: 10n; C_0805_2012Metric
D1, D2: 1N914; D_0805_2012Metric
D6: IN4001; D_1206_3216Metric
D7: 1N4001; D_1206_3216Metric
J1: Audio In; PinHeader_1x02_P2.54mm_Vertical
J3: RF/AGC Gain; PinHeader_1x03_P2.54mm_Vertical
J6: Audio Gain; PinHeader_1x03_P2.54mm_Vertical
J7: Audio Out; PinHeader_1x04_P2.54mm_Vertical
J8: Speaker; PinHeader_1x02_P2.54mm_Vertical
J17: Data; PinHeader_1x08_P2.54mm_Vertical
J18: Power; PinHeader_1x08_P2.54mm_Vertical
J19: Input; SMA_Amphenol_901-144_Vertical
JP1, JP2, JP3, JP4, JP5, JP6, JP7, JP8, JP9, JP10, JP11, JP12, JP13, JP14, JP15, JP16, JP17, JP18, JP19, JP20: Jumper_NO_Small; PinHeader_1x02_P2.54mm_Vertical
Q1, Q3, Q4, Q5: VN10LF; SOT-23
Q2: BCW89; SOT-23
R1, R3, R69, R70, R71, R72: 33K; R_0805_2012Metric
R2, R65, R66, R67, R68: 22K; R_0805_2012Metric
R4: 220K; R_0805_2012Metric
R5, R8, R9, R13, R18, R19, R20, R32, R33, R34, R35, R40, R41, R42, R43, R44, R57, R58, R59, R60, R83, R85: 10K; R_0805_2012Metric
R6, R7, R73, R74, R75, R76: 47K; R_0805_2012Metric
R10, R24, R26: 1K; R_0805_2012Metric
R11, R14: 36K; R_0805_2012Metric
R12: 1k; R_0805_2012Metric
R15: 47k; R_0805_2012Metric
R16, R21: 39K; R_0805_2012Metric
R17, R61, R62, R63, R64: 15K; R_0805_2012Metric
R22: 56K; R_0805_2012Metric
R23: 1K2; R_0805_2012Metric
R25: 10R; R_0805_2012Metric
R27, R30: 100K; R_0805_2012Metric
R28, R31: 120K; R_0805_2012Metric
R29: 470R; R_0805_2012Metric
R36, R37, R38, R39: 100R; R_0805_2012Metric
R45, R46, R47, R48: 3K3; R_0805_2012Metric
R49, R50, R51, R52: 4K7; R_0805_2012Metric
R53, R54, R55, R56, R84: 6K8; R_0805_2012Metric
R77, R78, R79, R80: 68K; R_0805_2012Metric
T1: Input; T50-2TrifilarTransformer
U1, U2, U3, U4, U5, U6, U7, U8, U9, U10: LM4562; DIP-8_W7.62mm
U11: LM386; DIP-8_W7.62mm
U12: FST3253; SOIC-16_3.9x9.9mm_P1.27mm
U13: AP1117-50; SOT-223-3_TabPin2
U14: TC7662Bx0A; SOIC-8_3.9x4.9mm_P1.27mm
U18: Si5351Module

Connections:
+5V: C114.1, C115.1, C118.1, J17.1, R85.1, U12.16, U13.2, U18.1
+12V: C36.1, C86.1, C88.1, C90.1, C92.1, C94.1, C97.1, C101.1, C102.1, C103.1, C104.1, C105.1, C112.1, D6.1, R83.1, U1.8, U2.8, U3.8, U4.8, U5.8, U6.8, U7.8, U8.8, U9.8, U10.8, U11.6, U13.3, U14.1, U14.8
-12V: C87.1, C89.1, C91.1, C93.1, C95.2, C98.1, C99.2, C100.1, C106.1, C107.1, C108.1, C109.1, C110.1, D7.2, U1.4, U2.4, U3.4, U4.4, U5.4, U6.4, U7.4, U8.4, U9.4, U10.4, U14.5
/Sheet6280C94B/AUDIOAGC: Q1.3, R27.1, R30.1, U3.2
/Sheet62579414/A: C53.2, JP5.2, R45.2
/Sheet62579414/B: C50.1, C57.2, R45.1, R49.2
/Sheet62579414/C: C54.1, C61.2, R49.1, R53.2
/Sheet62579414/D: C58.1, C65.2, R53.1, R57.2
/Sheet62579414/E: C62.1, C69.2, R57.1, R61.2
/Sheet62579414/F: C66.1, C73.2, R61.1, R65.2
/Sheet62579414/G: C70.1, C77.2, R65.1, R69.2
/Sheet62579414/H: C74.1, C81.2, R69.1, R73.2
/Sheet62579414/J: C78.1, C85.2, R73.1, R77.2
CWMUTE: D1.1, J17.4, R28.1
GND: C3.1, C5.2, C8.1, C10.2, C12.2, C14.1, C19.2, C23.1, C24.2, C26.2, C27.2, C36.2, C40.2, C41.2, C42.2, C43.2, C86.2, C87.2, C88.2, C89.2, C90.2, C91.2, C92.2, C93.2, C94.2, C95.1, C97.2, C98.2, C99.1, C100.2, C101.2, C102.2, C103.2, C104.2, C105.2, C106.2, C107.2, C108.2, C109.2, C110.2, C112.2, C114.2, C115.2, C116.2, C117.2, C118.2, J1.2, J3.3, J6.3, J7.4, J8.2, J17.8, J18.7, J18.8, J19.2, Q1.2, Q2.2, Q3.2, Q4.2, R10.2, R12.2, R16.2, R21.2, R84.2, T1.2, U1.2, U6.3, U6.5, U7.3, U7.5, U11.2, U11.4, U12.1, U12.8, U12.15, U13.1, U14.3, U18.2
Mix0Deg: C37.2, C40.1, JP13.2, JP20.2
Mix90Deg: C41.1, C44.2, JP14.2, JP19.2
Mix180Deg: C38.2, C42.1, JP15.2, JP18.2
Mix270Deg: C39.2, C43.1, JP16.2, JP17.2
unnamed: C1.1, R6.2, U2.1, U2.2
unnamed: C1.2, R1.2, R3.2
unnamed: C3.2, R3.1, U2.3
unnamed: C5.1, U1.6
unnamed: C6.1, C7.1, R11.2, U2.6, U2.7
unnamed: C6.2, C7.2, R6.1, R7.2
unnamed: C8.2, R7.1, U2.5
unnamed: C9.1, R17.1, R18.2, U5.1
unnamed: C9.2, R9.1, R13.2
unnamed: C11.1, C16.2, U4.1, U4.2
unnamed: C11.2, R11.1, R14.2
unnamed: C12.1, R13.1, U5.3
unnamed: C13.1, C15.2, R15.1, U3.1
unnamed: C13.2, J3.1
unnamed: C14.2, R14.1, U4.3
unnamed: C15.1, J6.1
unnamed: C16.1, C18.2, R19.2
unnamed: C17.1, C21.2, R22.1, U5.7
unnamed: C17.2, R18.1, R20.2
unnamed: C18.1, U4.5
unnamed: C19.1, R20.1, U5.5
unnamed: C20.1, R24.2
unnamed: C20.2, R19.1, U4.6, U4.7
unnamed: C21.1, R26.2
unnamed: C22.1, U11.8
unnamed: C22.2, R23.2
unnamed: C23.2, U11.7
unnamed: C24.1, R25.2
unnamed: C25.1, R25.1, U11.5
unnamed: C25.2, J7.2, R29.2
unnamed: C26.1, D1.2, Q3.1, R28.2
unnamed: C27.1, D2.2, Q4.1, R31.2
unnamed: C37.1, JP1.1
unnamed: C38.1, JP2.1
unnamed: C39.1, JP3.1
unnamed: C44.1, JP4.1
unnamed: C45.1, U14.2
unnamed: C45.2, U14.4
unnamed: C46.1, JP5.1, R41.1, U6.1
unnamed: C46.2, R36.1, R41.2, U6.2
unnamed: C47.1, JP6.1, R42.1, U6.7
unnamed: C47.2, R37.1, R42.2, U6.6
unnamed: C48.1, JP7.1, R43.1, U7.1
unnamed: C48.2, R38.1, R43.2, U7.2
unnamed: C49.1, JP8.1, R44.1, U7.7
unnamed: C49.2, R39.1, R44.2, U7.6
unnamed: C50.2, JP6.2, R46.2
unnamed: C51.1, C54.2, R46.1, R50.2
unnamed: C51.2, JP7.2, R47.2
unnamed: C52.1, C55.2, R47.1, R51.2
unnamed: C52.2, JP8.2, R48.2
unnamed: C53.1, C56.2, R48.1, R52.2
unnamed: C55.1, C58.2, R50.1, R54.2
unnamed: C56.1, C59.2, R51.1, R55.2
unnamed: C57.1, C60.2, R52.1, R56.2
unnamed: C59.1, C62.2, R54.1, R58.2
unnamed: C60.1, C63.2, R55.1, R59.2
unnamed: C61.1, C64.2, R56.1, R60.2
unnamed: C63.1, C66.2, R58.1, R62.2
unnamed: C64.1, C67.2, R59.1, R63.2
unnamed: C65.1, C68.2, R60.1, R64.2
unnamed: C67.1, C70.2, R62.1, R66.2
unnamed: C68.1, C71.2, R63.1, R67.2
unnamed: C69.1, C72.2, R64.1, R68.2
unnamed: C71.1, C74.2, R66.1, R70.2
unnamed: C72.1, C75.2, R67.1, R71.2
unnamed: C73.1, C76.2, R68.1, R72.2
unnamed: C75.1, C78.2, R70.1, R74.2
unnamed: C76.1, C79.2, R71.1, R75.2
unnamed: C77.1, C80.2, R72.1, R76.2
unnamed: C79.1, C82.2, R74.1, R78.2
unnamed: C80.1, C83.2, R75.1, R79.2
unnamed: C81.1, C84.2, R76.1, R80.2
unnamed: C82.1, R77.1, U8.3
unnamed: C83.1, R78.1, U8.5
unnamed: C84.1, R79.1, U9.3
unnamed: C85.1, R80.1, U9.5
unnamed: C111.1, R34.2, R35.2, R40.1, U10.2
unnamed: C113.1, J19.1
unnamed: C113.2, Q5.3, R83.2
unnamed: C117.1, R84.1, R85.2, T1.4, T1.5
unnamed: D6.2, J18.3
unnamed: D7.1, J18.1
unnamed: J3.2, Q2.1
unnamed: J6.2, U11.3
unnamed: J7.1, R29.1
unnamed: J7.3, J8.1
unnamed: JP1.2, R36.2
unnamed: JP2.2, R38.2
unnamed: JP3.2, R39.2
unnamed: JP4.2, R37.2
unnamed: JP9.1, U8.1, U8.2
unnamed: JP9.2, R32.1
unnamed: JP10.1, U8.6, U8.7
unnamed: JP10.2, R33.1
unnamed: JP11.1, U9.1, U9.2
unnamed: JP11.2, R34.1
unnamed: JP12.1, U9.6, U9.7
unnamed: JP12.2, R35.1
unnamed: JP13.1, U12.6
unnamed: JP14.1, U12.5
unnamed: JP15.1, U12.4
unnamed: JP16.1, U12.3
unnamed: JP17.1, U12.10
unnamed: JP18.1, U12.11
unnamed: JP19.1, U12.12
unnamed: JP20.1, U12.13
unnamed: Q3.3, R24.1, R27.2
unnamed: Q4.3, R26.1, R30.2
unnamed: Q5.2, T1.1
unnamed: R2.1, R4.2, U1.3
unnamed: R4.1, R5.2, U1.1
unnamed: R5.1, R8.2, U1.5
unnamed: R8.1, R9.2, U1.7
unnamed: R10.1, R15.2, U3.3
unnamed: R16.1, R17.2, U5.2
unnamed: R21.1, R22.2, U5.6
unnamed: R23.1, U11.1
unnamed: R32.2, R33.2, U10.3
unnamed: T1.3, U12.7
unnamed: T1.6, U12.9
unnamed: U12.2, U18.7
unnamed: U12.14, U18.6
PPOut: C111.2, J1.1, R1.1, R2.2, R40.2, U10.1
PTT: C116.1, J17.7, Q5.1
SCL: J17.5, U18.4
SDA: J17.6, U18.3
SMETER: C10.1, J17.2, Q1.1, Q2.3, R12.1
SSBMUTE: D2.1, J17.3, R31.1

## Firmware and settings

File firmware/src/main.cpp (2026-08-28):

/*
main.cpp for QRP transceiver V3 with Raspberry Pi Pico,
 SI5351 local oscillator and ILI9341 SPI display.
Using VSCode IDE with PlatformIO extension for development and upload.
Rotary encoder tuning with push button for frequency step, plus 3 additional push buttons for mode/band/misc
Display, rotary, push buttons and SI5351 code abstracted into libraries
*/

#include <Arduino.h>
#include <stddef.h>
#include <string.h>

#include <BoardControl.h>
#include <BandFilterControl.h>
#include <DisplayUI.h>
#include <PushButtons.h>
#include <RotaryInput.h>
#include <SI5351Control.h>

#include "hardware/flash.h"
#include "hardware/sync.h"

// SerialUSB = USB CDC (/dev/ttyACM0) on Arduino-Mbed Pico core
#if defined(SERIAL_PORT_USBVIRTUAL)
#define DBG_PORT SERIAL_PORT_USBVIRTUAL
#else
#define DBG_PORT SerialUSB
#endif

#define FW_TAG "HW_SPI_18_19_16_UI_V4"
using DisplayUI::Mode;

// SI5351 calibration (ppb):
// fine trim from measured 7,100,900 Hz at 7,100,000 Hz setpoint
// error = +900 Hz (~+126.8 ppm), so reduce magnitude of negative correction.
// Temporary correction tuned to bring the measured carrier close to the indicated frequency.
static constexpr int32_t SI5351_CORRECTION_PPB = -4610000;
// Extra post-calibration trim. Use this to nudge displayed vs measured LO
// after major synthesizer-mode changes (e.g. spread-spectrum disable).
// Latest trim from measured LO error.
// For LSB/USB in this firmware, LO should sit on the dial frequency; only CW is
// offset by the sidetone pitch. Use the midpoint of the last two trims so the
// residual error is centered around zero and normal temperature drift dominates.
static constexpr int32_t SI5351_CORRECTION_TRIM_PPB = 4602450;
static constexpr uint8_t SI5351_RX_I2C_ADDR = 0x60;
static constexpr uint8_t SI5351_TX_I2C_ADDR = 0x61;
static constexpr int32_t CW_PITCH_HZ = 700;
// S-meter input is inverted (higher voltage = weaker signal).
// Set the meter floor around 3.0V input:
// rawAdc(3.0V) ~= 4095 * (3.0 / 3.3) ~= 3723, so inverted sample ~= 4095 - 3723 ~= 372.
// Values at and below this are forced to zero before gain/log shaping.
static constexpr uint16_t S_METER_ZERO_RAW = 372;
static constexpr uint16_t S_METER_GAIN_PERMILLE = 1220;
static constexpr bool S_METER_LOG_RESPONSE = true;

// ── initial VFO state ────────────────────────────────────────────────────────────────
uint64_t vfoFreq     = 14200000UL;   // initial VFO frequency in Hz
Mode     currentMode = Mode::USB;
static constexpr uint64_t VFO_MIN_HZ = 1000000ULL;
static constexpr uint64_t VFO_MAX_HZ = 54000000ULL;

static const int32_t kStepTableHz[] = {1, 10, 100, 1000, 10000, 100000, 1000000};
static constexpr size_t kStepCount = sizeof(kStepTableHz) / sizeof(kStepTableHz[0]);
static uint8_t g_stepIndex = 3; // default 1000 Hz

static const uint64_t kBandDefaultHz[] = {
  1825900ULL,   // 160m
  3575000ULL,   // 80m
  7067000ULL,   // 40m
  10136000ULL,  // 30m
  14200000ULL,  // 20m
  18100000ULL,  // 17m
  21074000ULL,  // 15m
  24915000ULL,  // 12m
  28074000ULL,  // 10m
  50313000ULL   // 6m
};
static constexpr size_t kBandCount = sizeof(kBandDefaultHz) / sizeof(kBandDefaultHz[0]);
static const uint8_t kBandFilterCode[kBandCount] = {
  0, // 160m
  1, // 80m
  2, // 40m
  3, // 30m
  4, // 20m
  5, // 17m
  6, // 15m
  7, // 12m
  8, // 10m
  9  // 6m
};
static const Mode kBandDefaultMode[kBandCount] = {
  Mode::LSB, Mode::LSB, Mode::LSB, Mode::USB, Mode::USB,
  Mode::USB, Mode::USB, Mode::USB, Mode::USB, Mode::WSPR
};
static uint64_t g_bandFreqHz[kBandCount] = {
  1825900ULL, 3575000ULL, 7067000ULL, 10136000ULL, 14200000ULL,
  18100000ULL, 21074000ULL, 24915000ULL, 28074000ULL, 50313000ULL
};
static Mode g_bandMode[kBandCount] = {
  Mode::LSB, Mode::LSB, Mode::LSB, Mode::USB, Mode::USB,
  Mode::USB, Mode::USB, Mode::USB, Mode::USB, Mode::WSPR
};
static uint8_t g_bandIndex = 1;
static bool g_settingsDirty = false;
static bool g_txModeActive = false;
static bool g_softPowerOff = false;
static bool g_frequencyDisplayDirty = false;
static unsigned long g_lastTuneActivityMs = 0;

// ── Flash-backed settings ────────────────────────────────────────────────────
static constexpr uint32_t kSettingsMagic = 0x51525033UL; // "QRP3"
static constexpr uint16_t kSettingsVersion = 2;
static constexpr uint32_t kSettingsSlotAOffset = PICO_FLASH_SIZE_BYTES - (2 * FLASH_SECTOR_SIZE);
static constexpr uint32_t kSettingsSlotBOffset = PICO_FLASH_SIZE_BYTES - FLASH_SECTOR_SIZE;

enum class SettingsSlot : uint8_t { None, A, B };

struct SettingsRecord {
  uint32_t magic;
  uint16_t version;
  uint16_t length;
  uint32_t sequence;
  uint8_t currentBand;
  uint8_t currentMode;
  uint8_t stepIndex;
  uint8_t reserved0;
  uint64_t bandFreqHz[kBandCount];
  uint8_t bandMode[kBandCount];
  uint32_t checksum;
  uint8_t padding[FLASH_PAGE_SIZE - (4 + 2 + 2 + 4 + 1 + 1 + 1 + 1 + (8 * kBandCount) + (1 * kBandCount) + 2 + 4)];
};

static_assert(sizeof(SettingsRecord) == FLASH_PAGE_SIZE, "SettingsRecord must fit exactly in one flash page");

static SettingsSlot g_activeSettingsSlot = SettingsSlot::None;
static uint32_t g_settingsSequence = 0;

static uint64_t clampFrequency(uint64_t hz) {
  if (hz < VFO_MIN_HZ) return VFO_MIN_HZ;
  if (hz > VFO_MAX_HZ) return VFO_MAX_HZ;
  return hz;
}

static bool isValidModeValue(uint8_t modeValue) {
  switch (static_cast<Mode>(modeValue)) {
    case Mode::LSB:
    case Mode::USB:
    case Mode::CW:
    case Mode::FT8:
    case Mode::WSPR:
      return true;
    default:
      return false;
  }
}

static uint32_t fnv1a32(const uint8_t* data, size_t len) {
  uint32_t hash = 2166136261u;
  for (size_t i = 0; i < len; ++i) {
    hash ^= data[i];
    hash *= 16777619u;
  }
  return hash;
}

static uint32_t checksumForRecord(const SettingsRecord& record) {
  return fnv1a32(reinterpret_cast<const uint8_t*>(&record), offsetof(SettingsRecord, checksum));
}

static const SettingsRecord& settingsRecordAt(uint32_t flashOffset) {
  return *reinterpret_cast<const SettingsRecord*>(XIP_BASE + flashOffset);
}

static bool isRecordValid(const SettingsRecord& record) {
  if (record.magic != kSettingsMagic) return false;
  if (record.version != kSettingsVersion) return false;
  if (record.length != sizeof(SettingsRecord)) return false;
  if (record.currentBand >= kBandCount) return false;
  if (record.stepIndex >= kStepCount) return false;
  if (!isValidModeValue(record.currentMode)) return false;
  for (size_t i = 0; i < kBandCount; ++i) {
    if (!isValidModeValue(record.bandMode[i])) return false;
  }
  if (record.checksum != checksumForRecord(record)) return false;
  return true;
}

static void markSettingsDirty() {
  g_bandFreqHz[g_bandIndex] = clampFrequency(vfoFreq);
  g_bandMode[g_bandIndex] = currentMode;
  g_settingsDirty = true;
}

static bool isFrequencyValidForBand(size_t bandIndex, uint64_t hz) {
  if (bandIndex >= SI5351Control::kTxBandLimitCount) {
    return false;
  }

  const auto& range = SI5351Control::kTxBandLimitsHz[bandIndex];
  return hz >= range.low && hz <= range.high;
}

static void loadRecordIntoRuntime(const SettingsRecord& record) {
  for (size_t i = 0; i < kBandCount; ++i) {
    const uint64_t candidate = record.bandFreqHz[i];
    g_bandFreqHz[i] = isFrequencyValidForBand(i, candidate)
      ? candidate
      : kBandDefaultHz[i];

    g_bandMode[i] = isValidModeValue(record.bandMode[i])
      ? static_cast<Mode>(record.bandMode[i])
      : kBandDefaultMode[i];
  }

  g_bandIndex = record.currentBand;
  g_stepIndex = record.stepIndex;
  currentMode = g_bandMode[g_bandIndex];
  vfoFreq = g_bandFreqHz[g_bandIndex];
}

static void loadSettingsFromFlash() {
  const SettingsRecord& slotA = settingsRecordAt(kSettingsSlotAOffset);
  const SettingsRecord& slotB = settingsRecordAt(kSettingsSlotBOffset);
  const bool validA = isRecordValid(slotA);
  const bool validB = isRecordValid(slotB);

  if (!validA && !validB) {
    DBG_PORT.println("[SAVE] No valid saved settings found; using defaults");
    g_activeSettingsSlot = SettingsSlot::None;
    g_settingsSequence = 0;
    g_settingsDirty = false;
    return;
  }

  const SettingsRecord* chosen = &slotA;
  g_activeSettingsSlot = SettingsSlot::A;
  if (!validA || (validB && slotB.sequence > slotA.sequence)) {
    chosen = &slotB;
    g_activeSettingsSlot = SettingsSlot::B;
  }

  loadRecordIntoRuntime(*chosen);
  g_settingsSequence = chosen->sequence;
  g_settingsDirty = false;

  DBG_PORT.print("[SAVE] Restored slot ");
  DBG_PORT.print((g_activeSettingsSlot == SettingsSlot::A) ? 'A' : 'B');
  DBG_PORT.print(" seq=");
  DBG_PORT.print(g_settingsSequence);
  DBG_PORT.print(" band=");
  DBG_PORT.print(g_bandIndex);
  DBG_PORT.print(" freq=");
  DBG_PORT.print((uint32_t)vfoFreq);
  DBG_PORT.print(" mode=");
  DBG_PORT.println(DisplayUI::modeName(currentMode));
}

static SettingsRecord makeSettingsRecord(uint32_t nextSequence) {
  SettingsRecord record{};
  record.magic = kSettingsMagic;
  record.version = kSettingsVersion;
  record.length = sizeof(SettingsRecord);
  record.sequence = nextSequence;
  record.currentBand = g_bandIndex;
  record.currentMode = static_cast<uint8_t>(currentMode);
  record.stepIndex = g_stepIndex;
  for (size_t i = 0; i < kBandCount; ++i) {
    record.bandFreqHz[i] = g_bandFreqHz[i];
    record.bandMode[i] = static_cast<uint8_t>(g_bandMode[i]);
  }
  record.checksum = checksumForRecord(record);
  return record;
}

static bool saveSettingsIfDirty(const char* reason) {
  if (!g_settingsDirty) {
    DBG_PORT.print("[SAVE] Skipped (");
    DBG_PORT.print(reason);
    DBG_PORT.println("): no changes");
    return true;
  }

  markSettingsDirty();
  const SettingsSlot targetSlot = (g_activeSettingsSlot == SettingsSlot::A) ? SettingsSlot::B : SettingsSlot::A;
  const uint32_t targetOffset = (targetSlot == SettingsSlot::A) ? kSettingsSlotAOffset : kSettingsSlotBOffset;
  const SettingsRecord record = makeSettingsRecord(g_settingsSequence + 1);

  DBG_PORT.print("[SAVE] Writing slot ");
  DBG_PORT.print((targetSlot == SettingsSlot::A) ? 'A' : 'B');
  DBG_PORT.print(" seq=");
  DBG_PORT.print(record.sequence);
  DBG_PORT.print(" reason=");
  DBG_PORT.println(reason);
  DBG_PORT.flush();

  const uint32_t savedInterrupts = save_and_disable_interrupts();
  flash_range_erase(targetOffset, FLASH_SECTOR_SIZE);
  flash_range_program(targetOffset, reinterpret_cast<const uint8_t*>(&record), sizeof(SettingsRecord));
  restore_interrupts(savedInterrupts);

  const SettingsRecord& verify = settingsRecordAt(targetOffset);
  if (!isRecordValid(verify) || verify.sequence != record.sequence) {
    DBG_PORT.println("[SAVE] Verify failed");
    return false;
  }

  g_activeSettingsSlot = targetSlot;
  g_settingsSequence = record.sequence;
  g_settingsDirty = false;
  DBG_PORT.println("[SAVE] Complete");
  return true;
}

static bool reverseQuadratureForMode(Mode mode) {
  switch (mode) {
    case Mode::USB:
    case Mode::FT8:
    case Mode::WSPR:
      return true;
    case Mode::LSB:
    case Mode::CW:
    default:
      return false;
  }
}

static uint64_t loFrequencyForMode(uint64_t dialHz, Mode mode) {
  if (mode != Mode::CW) {
    return dialHz;
  }

  // CW-L convention: LO is below dial frequency by audio pitch.
  if (dialHz > static_cast<uint64_t>(CW_PITCH_HZ)) {
    return dialHz - static_cast<uint64_t>(CW_PITCH_HZ);
  }
  return VFO_MIN_HZ;
}

static void applyMuteOutputs() {
  if (g_txModeActive) {
    BoardControl::setMute(BoardControl::MuteOutput::RxMute, true);
    BoardControl::setMute(BoardControl::MuteOutput::SsbMute, true);
    BoardControl::setMute(BoardControl::MuteOutput::CwMute, true);
    return;
  }

  bool cwMute = false;
  bool ssbMute = true;
  if (currentMode == Mode::LSB ||
      currentMode == Mode::USB ||
      currentMode == Mode::FT8 ||
      currentMode == Mode::WSPR) {
    cwMute = true;
    ssbMute = false;
  } else if (currentMode == Mode::CW) {
    cwMute = false;
    ssbMute = true;
  }

  BoardControl::setMute(BoardControl::MuteOutput::RxMute, false);
  BoardControl::setMute(BoardControl::MuteOutput::CwMute, cwMute);
  BoardControl::setMute(BoardControl::MuteOutput::SsbMute, ssbMute);
}

static void applyBandFilter() {
  if (!BandFilterControl::applyForBand(g_bandIndex)) {
    DBG_PORT.println("[FLT] Failed to apply band filter selection");
    return;
  }

  DBG_PORT.print("[FLT] Band ");
  DBG_PORT.print(g_bandIndex);
  DBG_PORT.print(" -> filter ");
  DBG_PORT.println(BandFilterControl::currentFilterIndex());
}

static void applyVfo(bool liveRetune = true, bool updateDisplay = true) {
  const uint64_t loHz = loFrequencyForMode(vfoFreq, currentMode);

  // Briefly mute RX audio while the SI5351 is being retuned.
  // The clock chip can be reprogrammed live, but PLL/output resets create
  // audible clicks if the analog chain is left unmuted.
  BoardControl::setMute(BoardControl::MuteOutput::RxMute, true);
  delayMicroseconds(150);

  SI5351Control::setQuadrature90(SI5351Control::Device::Rx,
                                 loHz,
                                 reverseQuadratureForMode(currentMode),
                                 liveRetune);

  delayMicroseconds(150);
  applyMuteOutputs();
  if (updateDisplay) {
    DisplayUI::updateFrequencyDisplay(vfoFreq, currentMode);
    g_frequencyDisplayDirty = false;
  }
}

static void flushPendingTuneDelta(int32_t tuneSteps, int8_t tuneDir) {
  if (tuneSteps == 0) {
    return;
  }

  int64_t next = static_cast<int64_t>(vfoFreq)
    + static_cast<int64_t>(tuneSteps) * RotaryInput::stepHz();
  if (next < static_cast<int64_t>(VFO_MIN_HZ)) next = static_cast<int64_t>(VFO_MIN_HZ);
  if (next > static_cast<int64_t>(VFO_MAX_HZ)) next = static_cast<int64_t>(VFO_MAX_HZ);

  vfoFreq = static_cast<uint64_t>(next);
  g_bandFreqHz[g_bandIndex] = vfoFreq;
  g_lastTuneActivityMs = millis();

  applyVfo(true, false);
  DisplayUI::flashTuneDirection(tuneDir);
  g_frequencyDisplayDirty = true;
  g_settingsDirty = true;
}

static void setDisplayBacklight(bool on) {
  digitalWrite(DisplayUI::TFT_BL, on ? HIGH : LOW);
}

static void enterSoftPowerOff() {
  if (g_softPowerOff) {
    return;
  }

  DBG_PORT.println("[PWR] Shutdown requested");
  saveSettingsIfDirty("Power down");

  g_txModeActive = false;
  BoardControl::setMute(BoardControl::MuteOutput::RxMute, true);
  BoardControl::setMute(BoardControl::MuteOutput::SsbMute, true);
  BoardControl::setMute(BoardControl::MuteOutput::CwMute, true);

  SI5351Control::enableOutput(SI5351Control::Device::Rx, false);
  SI5351Control::enableOutput(SI5351Control::Device::Tx, false);

  BandFilterControl::setFilterIndex(0);
  DisplayUI::enterLowPower();
  setDisplayBacklight(false);
  digitalWrite(LED_BUILTIN, LOW);

  g_softPowerOff = true;
  DBG_PORT.println("[PWR] Soft power OFF (short POWER press to wake)");
}

static void exitSoftPowerOff() {
  if (!g_softPowerOff) {
    return;
  }

  DBG_PORT.println("[PWR] Wake requested");
  setDisplayBacklight(true);
  DisplayUI::exitLowPower();
  DisplayUI::drawMainScreen();
  DisplayUI::updateStepDisplay(kStepTableHz[g_stepIndex]);

  SI5351Control::enableOutput(SI5351Control::Device::Rx, true);
  SI5351Control::enableOutput(SI5351Control::Device::Tx, false);
  applyBandFilter();
  applyMuteOutputs();
  applyVfo(false);

  g_softPowerOff = false;
  DBG_PORT.println("[PWR] Soft power ON");
}

static void cycleMode() {
  switch (currentMode) {
    case Mode::LSB:  currentMode = Mode::USB;  break;
    case Mode::USB:  currentMode = Mode::CW;   break;
    case Mode::CW:   currentMode = Mode::FT8;  break;
    case Mode::FT8:  currentMode = Mode::WSPR; break;
    case Mode::WSPR: currentMode = Mode::LSB;  break;
    default:         currentMode = Mode::LSB;  break;
  }
  applyVfo(true);
  markSettingsDirty();
  applyMuteOutputs();

  const bool cwMute = BoardControl::isMuted(BoardControl::MuteOutput::CwMute);
  const bool ssbMute = BoardControl::isMuted(BoardControl::MuteOutput::SsbMute);
  DBG_PORT.print("[MUTE] Mode=");
  DBG_PORT.print(DisplayUI::modeName(currentMode));
  DBG_PORT.print(" CWMUTE=");
  DBG_PORT.print(cwMute);
  DBG_PORT.print(" SSB=");
  DBG_PORT.println(ssbMute);
}

static void cycleBand() {
  g_bandFreqHz[g_bandIndex] = clampFrequency(vfoFreq);
  g_bandMode[g_bandIndex] = currentMode;
  g_bandIndex = (g_bandIndex + 1) % kBandCount;
  vfoFreq = g_bandFreqHz[g_bandIndex];
  currentMode = g_bandMode[g_bandIndex];
  applyBandFilter();
  applyVfo(false);
  markSettingsDirty();
  saveSettingsIfDirty("Band change");
}

static void cycleStep() {
  g_stepIndex = (g_stepIndex + 1) % kStepCount;
  RotaryInput::setStepHz(kStepTableHz[g_stepIndex]);
  DisplayUI::updateStepDisplay(kStepTableHz[g_stepIndex]);
  DisplayUI::triggerStepDigitFlash(kStepTableHz[g_stepIndex], 500);
  DisplayUI::updateFrequencyDisplay(vfoFreq, currentMode);
  markSettingsDirty();
}
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
void loop() {
  // Run control scanning at a fixed 100 Hz cadence instead of every loop
  // iteration to avoid high-rate deterministic load modulation.
  static unsigned long s_lastControlPollUs = 0;
  const unsigned long nowUs = micros();
  if (static_cast<uint32_t>(nowUs - s_lastControlPollUs) >= 10000U) {
    s_lastControlPollUs = nowUs;
    BoardControl::update();
  }

  if (g_softPowerOff) {
    BoardControl::Command offCommand{};
    while (BoardControl::read(offCommand)) {
      if (offCommand.type == BoardControl::CommandType::PowerShortPress) {
        exitSoftPowerOff();
      }
    }

#if defined(__arm__) || defined(__thumb__)
    __WFI();
#else
    delay(20);
#endif
    return;
  }

  static unsigned long lastLog = 0;
  if (millis() - lastLog >= 5000) {
    lastLog = millis();
    DBG_PORT.print("alive Sraw=");
    DBG_PORT.print(BoardControl::readSMeterRaw());
    DBG_PORT.print(" Savg100ms=");
    DBG_PORT.print(BoardControl::readSMeterAveragedRaw());
    DBG_PORT.print(" Speak5s=");
    DBG_PORT.println(BoardControl::readSMeterPeak5sRaw());
  }

  static unsigned long lastSMeterUiMs = 0;
  const unsigned long now = millis();
  const bool tuningActive = static_cast<unsigned long>(now - g_lastTuneActivityMs) < 120UL;
  if (!tuningActive && (now - lastSMeterUiMs >= 100)) {
    lastSMeterUiMs = millis();
    DisplayUI::updateSMeterDisplay(BoardControl::readSMeterAveragedRaw(),
                                   BoardControl::readSMeterPeak5sRaw());
  }

  static unsigned long lastFreqUiMs = 0;
  if (g_frequencyDisplayDirty && (now - lastFreqUiMs >= 40UL)) {
    lastFreqUiMs = now;
    DisplayUI::updateFrequencyDisplay(vfoFreq, currentMode);
    g_frequencyDisplayDirty = false;
  }

  static unsigned long lastFreqFlashUiMs = 0;
  if (DisplayUI::isStepDigitFlashActive() && (millis() - lastFreqFlashUiMs >= 120)) {
    lastFreqFlashUiMs = millis();
    DisplayUI::updateFrequencyDisplay(vfoFreq, currentMode);
  }

  BoardControl::Command command{};
  int32_t pendingTuneSteps = 0;
  int8_t pendingTuneDir = 0;
  while (BoardControl::read(command)) {
    switch (command.type) {
      case BoardControl::CommandType::TuneDelta: {
        pendingTuneSteps += command.value;
        pendingTuneDir = (command.value > 0) ? +1 : -1;
        break;
      }
      case BoardControl::CommandType::CycleMode:
        flushPendingTuneDelta(pendingTuneSteps, pendingTuneDir);
        pendingTuneSteps = 0;
        cycleMode();
        break;
      case BoardControl::CommandType::CycleBand:
        flushPendingTuneDelta(pendingTuneSteps, pendingTuneDir);
        pendingTuneSteps = 0;
        cycleBand();
        break;
      case BoardControl::CommandType::CycleStep:
        flushPendingTuneDelta(pendingTuneSteps, pendingTuneDir);
        pendingTuneSteps = 0;
        cycleStep();
        break;
      case BoardControl::CommandType::SaveSettings:
        flushPendingTuneDelta(pendingTuneSteps, pendingTuneDir);
        pendingTuneSteps = 0;
        saveSettingsIfDirty("Fn button");
        break;
      case BoardControl::CommandType::ToggleTxRx: {
        flushPendingTuneDelta(pendingTuneSteps, pendingTuneDir);
        pendingTuneSteps = 0;
        g_txModeActive = !g_txModeActive;
        applyMuteOutputs();
        DBG_PORT.print("[MUTE] TX mode ");
        DBG_PORT.println(g_txModeActive ? "ON (CWMUTE/RXMUTE/SSBMUTE all HIGH)"
                                        : "OFF (RX mode mutes restored)");
        break;
      }
      case BoardControl::CommandType::PowerLongPress:
        flushPendingTuneDelta(pendingTuneSteps, pendingTuneDir);
        pendingTuneSteps = 0;
        enterSoftPowerOff();
        break;
      case BoardControl::CommandType::PowerShortPress:
        // Short POWER presses are only used for wake while in soft-off state.
        break;
      case BoardControl::CommandType::None:
      default:
        break;
    }
  }

  flushPendingTuneDelta(pendingTuneSteps, pendingTuneDir);
}

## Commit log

2026-04-22 Add files via upload
    Receiver board KICAD files
    [QRPTransceiver-B_Cu.gbr, QRPTransceiver-B_Mask.gbr, QRPTransceiver-B_Paste.gbr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]
2026-05-16 Add bring-up, calibration, and pinout documentation and expand .gitignore for KiCad and PlatformIO artifacts
2026-05-16 chore: archive legacy and backup root files
    Agent-Logs-Url: https://github.com/richardhosking/QRPTransceiver/sessions/2329a8e4-cee6-4c88-bb25-dfe96806a3fa
    [QRPTransceiver.sch, QRPTransceivercopy.kicad_pcb, ReceiverAudio.sch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]
2026-05-16 Reorganize outputs and reference materials into hardware/outputs and reference
    [QRPTransceiver-B_Cu.gbr, QRPTransceiver-B_Mask.gbr, QRPTransceiver-B_Paste.gbr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]
2026-05-16 Move KiCad project files into hardware/kicad
    [QRPTransceiver.kicad_pcb, QRPTransceiver.kicad_sch, ReceiverAudio.kicad_sch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]
2026-05-16 Recover mixer in Kicad Schematic
    [file637AC237.kicad_sch]
2026-05-17 added transmit and receive board control logic
2026-05-23 Add power button behavior and power latch documentation
2026-05-23 Power cicuit in KICAD
2026-07-03 Firmware: encoder ISR queue, S-meter calibration, UI polish, SI5351 fixes
    Firmware changes:
    - RotaryInput: rewrite to interrupt-driven ISR queue (RP2040 GPIO callback,
    64-event ring buffer). Eliminates ~2-3 step/sec polling limit.
    - SI5351Control: add liveRetune param to setQuadrature90(). Live-retune path
    skips PLL reset and output disable/enable to eliminate audio transients.
    Both CLK0/CLK1 forced to PLLA for phase coherence. Phase registers zeroed
    in all low-band paths.
    - BoardControl: S-meter ADC inversion (higher V = weaker signal), configurable
    zero-raw floor, gain permille, and optional sqrt log companding.
    - main.cpp: analogReadResolution(12) for 12-bit ADC. S_METER_ZERO_RA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
    [QRPTransceiver.kicad_pcb, ReceiverAudio.kicad_sch, file637AC237.kicad_sch]
2026-08-28 Fixed quadrature generation PCB excirt circuit in draft
    [FrontendMixer.kicad_sch, QRPTransceiver.kicad_sch, ReceiverAudio.kicad_sch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]
2026-08-29 Document SSC notes reference in CURRENT_SI5351_APPROACH.md
    [FrontendMixer.kicad_sch, ReceiverAudio.kicad_sch, controller.kicad_sch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]
2026-08-29 Backup POWER_SWITCH_CIRCUIT and add processor power schematic draft
2026-08-29 Add controller sheet draft for processor power-latch
2026-08-29 Add KiCad schematic sheet draft for controller power-latch
    [POWER_CIRCUIT_CONTROLLER_SHEET.kicad_sch]
2026-08-29 Fix kicad sheet syntax: remove malformed comment/text element
    [POWER_CIRCUIT_CONTROLLER_SHEET.kicad_sch]
2026-08-29 Fix kicad sheet top-level parentheses
    [POWER_CIRCUIT_CONTROLLER_SHEET.kicad_sch]
2026-08-29 Make kicad sheet minimal and use valid comment string
    [POWER_CIRCUIT_CONTROLLER_SHEET.kicad_sch]
2026-08-29 Simplify kicad sheet: remove title_block to avoid comment parsing issues
    [POWER_CIRCUIT_CONTROLLER_SHEET.kicad_sch]
2026-08-29 Sanitize kicad sheet: minimal, well-formed S-expression
    [POWER_CIRCUIT_CONTROLLER_SHEET.kicad_sch]
2026-08-29 Replace controller power sheet with minimal, validated kicad_sch
    [POWER_CIRCUIT_CONTROLLER_SHEET.kicad_sch]
2026-08-29 Replace controller sheet with minimal KiCad-8 compatible schematic
    [POWER_CIRCUIT_CONTROLLER_SHEET.kicad_sch]
2026-08-29 Consolidate controller power sheet to single KiCad-8 compatible schematic
    [POWER_CIRCUIT_CONTROLLER_SHEET.kicad_sch]
2026-08-29 Clean kicad sheet: remove comments and ensure top-level '(' at column 1
    [POWER_CIRCUIT_CONTROLLER_SHEET.kicad_sch]
2026-08-29 Temporary: remove symbols to avoid lib_id parsing error; minimal sheet
    [POWER_CIRCUIT_CONTROLLER_SHEET.kicad_sch]
2026-08-29 Add placeholder symbol to satisfy KiCad parser
    [POWER_CIRCUIT_CONTROLLER_SHEET.kicad_sch]
2026-08-29 Fix symbol entries: add required in_bom/on_board tokens for KiCad8 parser
    [POWER_CIRCUIT_CONTROLLER_SHEET.kicad_sch]
2026-09-23 Save local KiCad edits
    [controller.kicad_sch]
